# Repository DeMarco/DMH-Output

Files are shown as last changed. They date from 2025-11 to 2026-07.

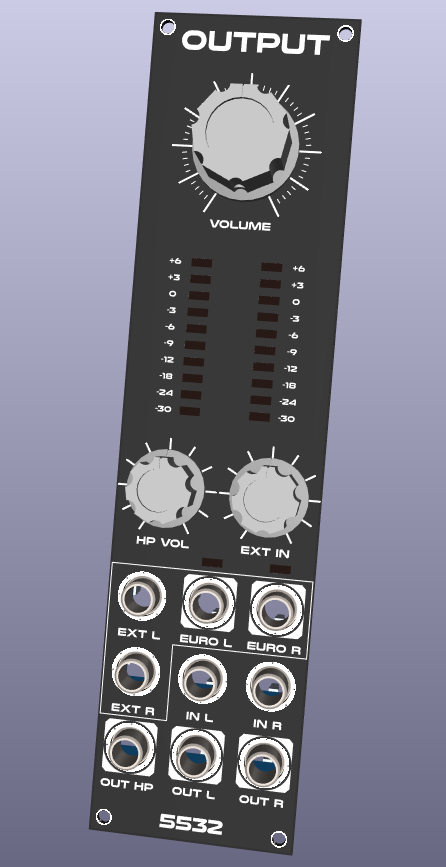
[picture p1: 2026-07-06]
Images/panel.png

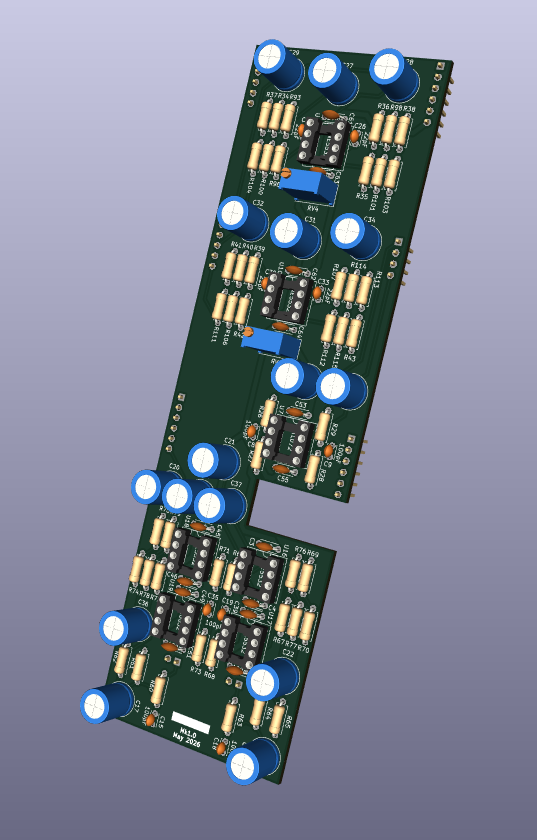
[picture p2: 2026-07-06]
Images/mezzanine_back.png

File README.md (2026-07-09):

# DMH-Output
Kosmo format output module







## Features

### Line outputs and main volume

The L and R inputs accept the usual (Eurorack) modular synth audio amplitude of 10 V peak-to-peak.
The line level L and R outputs accept both balanced TRS and unbalanced TS cables.
The main volume control affects both L and R channels. The reduction factor can be set from from -infinite (silence) to -3 dB (max).
Since the usual 10 Vpp amplitude corresponds to around +13 dBu, this means the module can output from -infinite up to +10 dBu.
The precision dBu meter will max out at +6 dBu (red LED). Most professional audio equipment like mixers and audio interfaces expect a nominal input line level of +4 dBu.

### Headphone output

There's a separate stereo (TRS) headphone driving output with its own volume control, also with a range of -infinite to +10 dBu.
It can drive headphones with 32ohms or 85ohms with no problem. Higher impedances are also probably fine.

### External instrument inputs

The external inputs can amplify line level signals to the usual Eurorack amplitude of 10 Vpp with the help of a dedicated volume control. The input metering LEDs will turn yellow when the amplified signals at the Euro L and R outputs is between 9 and 11 Vpp, and red when above 11 Vpp.
This pre-amp has been designed with line level signals in mind, like those coming from another synthesizer or professional audio equipment. High impedance instrument outputs like electric guitars might not produce the best sound when connected directly to this module.

## Current consumption

+12V --> 110mA

-12V --> 110mA

## Dimensions

Height: 20cm

Width: 5cm

Depth: 5cm

## PCB set

- Front Panel
- Controls
- LEDs Aligner
- Main
- Mezzanine

## Gerbers

https://github.com/DeMarco/DMH-Output/tree/main/Gerbers

## Schematic and BoM

https://github.com/DeMarco/DMH-Output/blob/main/DMH_Output_Schematic.pdf

https://github.com/DeMarco/DMH-Output/blob/main/DMH_Output_BoM.csv

## Assembly and Calibration Instructions

https://github.com/DeMarco/DMH-Output/blob/main/Assembly_Instructions.md

## Font

For viewing/customizing in KiCad, I recommend downloading and installing the Nulshock font from Typodermic: https://typodermicfonts.com/nulshock/

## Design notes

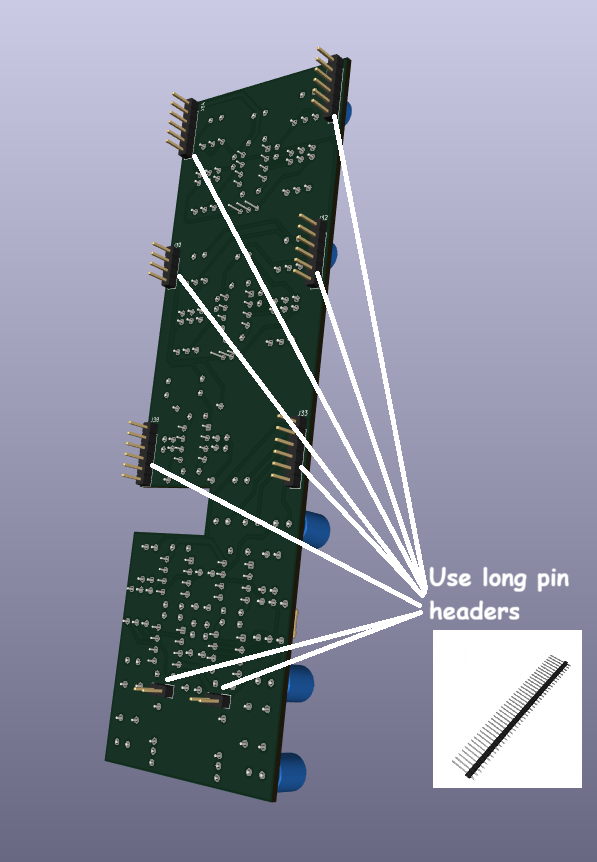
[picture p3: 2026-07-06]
Images/mezzanine_front.png

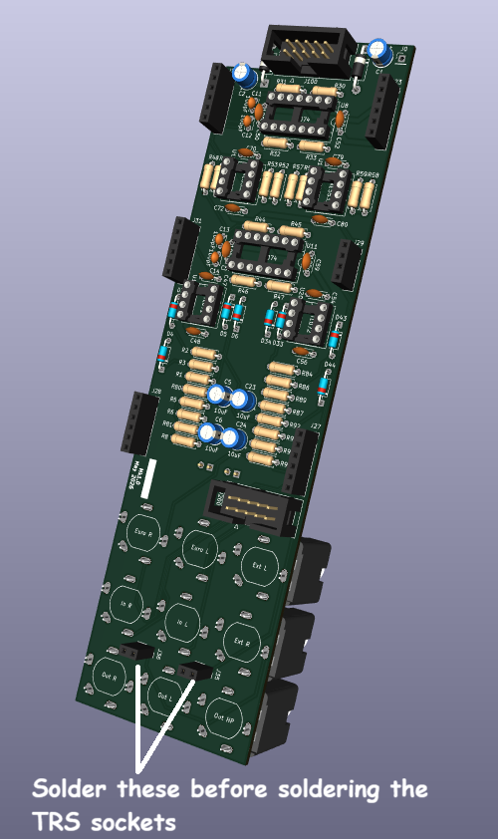
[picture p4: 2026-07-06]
Images/main_back.png

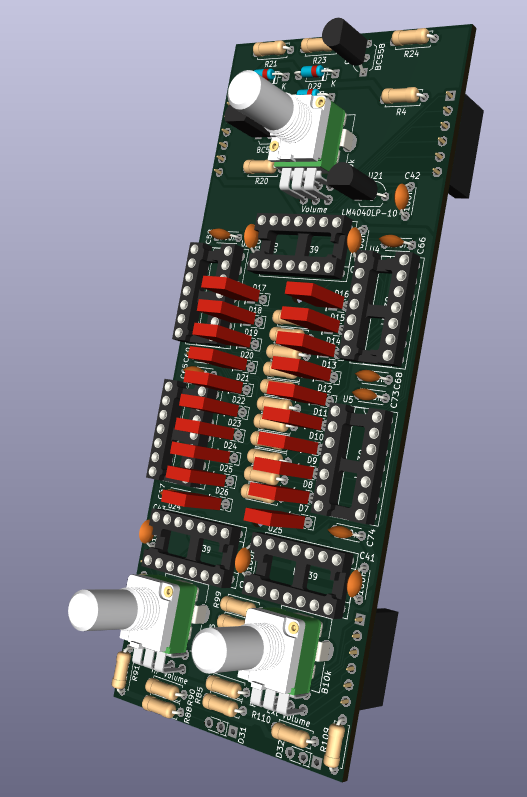
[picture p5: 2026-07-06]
Images/controls_front.png

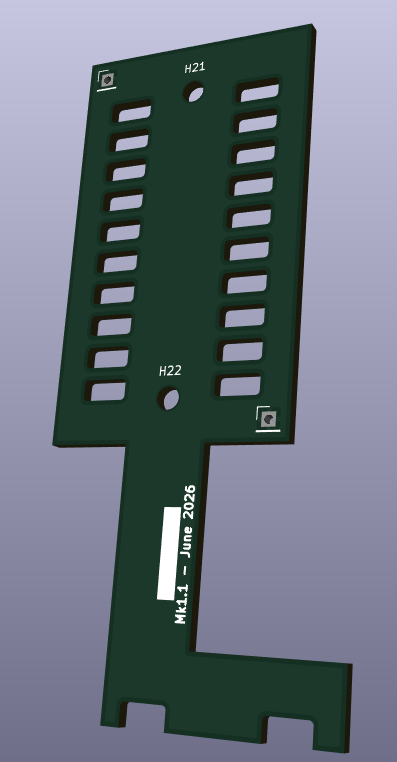
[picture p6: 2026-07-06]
Images/LED_aligner.png

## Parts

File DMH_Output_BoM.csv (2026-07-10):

Reference | Value | Qty | Footprint
C8,C9,C11,C12,C13,C14,C15,C18,C19,C35 | 100pF | 10 | Capacitor_THT:C_Disc_D3.0mm_W2.0mm_P2.50mm
C25,C26,C30,C33 | 22pF 50V | 4 | Capacitor_THT:C_Disc_D3.0mm_W2.0mm_P2.50mm
C3,C4,C39,C40,C41,C42,C43,C44,C45,C46,C47,C48,C49,C50,C51,C52,C53,C54,C55,C56,C57,C58,C59,C60,C61,C62,C63,C64,C65,C66,C67,C68,C70,C72,C73,C74,C77,C78,C79,C80 | 100nF | 40 | Capacitor_THT:C_Disc_D4.3mm_W1.9mm_P5.00mm
C16,C17,C20,C21 | 22uF 35V | 4 | Capacitor_THT:C_Radial_D8.0mm_H11.5mm_P3.50mm | Nichikon non-polarized
C7,C10,C22,C27,C28,C29,C31,C32,C34,C36,C37,C38 | 47uF 35V | 12 | Capacitor_THT:C_Radial_D8.0mm_H11.5mm_P3.50mm | Nichikon non-polarized
C5,C6,C23,C24 | 10uF | 4 | Capacitor_THT:CP_Radial_D5.0mm_P2.00mm
C1,C2 | 47uF | 2 | Capacitor_THT:CP_Radial_D5.0mm_P2.00mm
J24,J25 | Conn_01x02 | 2 | Connector_PinHeader_2.54mm:PinHeader_1x02_P2.54mm_Vertical
J39,J40 | Conn_01x02_PinHeader | 2 | Connector_PinHeader_2.54mm:PinHeader_1x02_P2.54mm_Vertical
J30 | Conn_01x04_PinHeader | 1 | Connector_PinHeader_2.54mm:PinHeader_1x04_P2.54mm_Vertical
J33,J34,J37,J38 | Conn_01x06 | 4 | Connector_PinHeader_2.54mm:PinHeader_1x06_P2.54mm_Vertical
J32 | Conn_01x06_PinHeader | 1 | Connector_PinHeader_2.54mm:PinHeader_1x06_P2.54mm_Vertical
J21,J22 | Conn_01x02 | 2 | Connector_PinSocket_2.54mm:PinSocket_1x02_P2.54mm_Vertical
J35,J36 | Conn_01x02_PinHeader | 2 | Connector_PinSocket_2.54mm:PinSocket_1x02_P2.54mm_Vertical
J29 | Conn_01x04_PinHeader | 1 | Connector_PinSocket_2.54mm:PinSocket_1x04_P2.54mm_Vertical
J10,J13,J23,J28 | Conn_01x06 | 4 | Connector_PinSocket_2.54mm:PinSocket_1x06_P2.54mm_Vertical
J11,J12,J26,J27,J31 | Conn_01x06_PinHeader | 5 | Connector_PinSocket_2.54mm:PinSocket_1x06_P2.54mm_Vertical
D3,D4,D5,D6,D27,D28,D29,D30,D33,D34,D43,D44 | 1N4148 | 12 | Diode_THT:D_DO-35_SOD27_P7.62mm_Horizontal
D1,D2 | SB140 | 2 | Diode_THT:D_DO-41_SOD81_P10.16mm_Horizontal
D7,D8,D9,D10,D11,D12,D13,D20,D21,D22,D23,D24,D25,D26 | LED_G | 14 | LED_THT:LED_Rectangular_W5.0mm_H2.0mm
D16,D17 | LED_R | 2 | LED_THT:LED_Rectangular_W5.0mm_H2.0mm
D14,D15,D18,D19 | LED_Y | 4 | LED_THT:LED_Rectangular_W5.0mm_H2.0mm
D31,D32 | LED_Dual_AKA | 2 | LED_THT:LED_Rectangular_W5.0mm_H2.0mm-3Pins
U2,U3,U4,U5,U6,U24,U25 | LM339 | 7 | Package_DIP:DIP-14_W7.62mm_Socket
U8,U11 | TL074 | 2 | Package_DIP:DIP-14_W7.62mm_Socket
U9,U10,U13,U15,U16,U17,U18,U19 | NE5532 | 8 | Package_DIP:DIP-8_W7.62mm_Socket
U1,U7,U20 | TL072 | 3 | Package_DIP:DIP-8_W7.62mm_Socket
Q1,Q2 | BC558 | 2 | Package_TO_SOT_THT:TO-92L_Inline_Wide
U21 | LM4040LP-10 | 1 | Package_TO_SOT_THT:TO-92L_Inline_Wide
RV4,RV5 | 1k | 2 | Potentiometer_THT:Potentiometer_Bourns_3296W_Vertical
R52,R53,R58,R59 | 10R | 4 | Resistor_THT:R_Axial_DIN0207_L6.3mm_D2.5mm_P7.62mm_Horizontal
R21,R23 | 47R | 2 | Resistor_THT:R_Axial_DIN0207_L6.3mm_D2.5mm_P7.62mm_Horizontal
R37,R38,R41,R113 | 75R | 4 | Resistor_THT:R_Axial_DIN0207_L6.3mm_D2.5mm_P7.62mm_Horizontal
R60,R63,R70,R74 | 100R | 4 | Resistor_THT:R_Axial_DIN0207_L6.3mm_D2.5mm_P7.62mm_Horizontal
R18,R19 | 361R | 2 | Resistor_THT:R_Axial_DIN0207_L6.3mm_D2.5mm_P7.62mm_Horizontal
R3,R6,R86,R94 | 470R | 4 | Resistor_THT:R_Axial_DIN0207_L6.3mm_D2.5mm_P7.62mm_Horizontal
R17 | 715R | 1 | Resistor_THT:R_Axial_DIN0207_L6.3mm_D2.5mm_P7.62mm_Horizontal
R30,R31,R32,R33,R43,R44,R46,R48,R49,R56,R57,R67,R72,R103,R104,R108,R111 | 1k | 17 | Resistor_THT:R_Axial_DIN0207_L6.3mm_D2.5mm_P7.62mm_Horizontal
R15 | 1k2 | 1 | Resistor_THT:R_Axial_DIN0207_L6.3mm_D2.5mm_P7.62mm_Horizontal
R16 | 1k43 | 1 | Resistor_THT:R_Axial_DIN0207_L6.3mm_D2.5mm_P7.62mm_Horizontal
R14 | 1k69 | 1 | Resistor_THT:R_Axial_DIN0207_L6.3mm_D2.5mm_P7.62mm_Horizontal
R76,R77,R78,R79 | 2k | 4 | Resistor_THT:R_Axial_DIN0207_L6.3mm_D2.5mm_P7.62mm_Horizontal
R13 | 2k37 | 1 | Resistor_THT:R_Axial_DIN0207_L6.3mm_D2.5mm_P7.62mm_Horizontal
R4,R12,R88,R90,R109,R110 | 3k3 | 6 | Resistor_THT:R_Axial_DIN0207_L6.3mm_D2.5mm_P7.62mm_Horizontal
R11,R34,R35,R40,R42,R96,R98,R112,R114 | 4k7 | 9 | Resistor_THT:R_Axial_DIN0207_L6.3mm_D2.5mm_P7.62mm_Horizontal
R10 | 6k8 | 1 | Resistor_THT:R_Axial_DIN0207_L6.3mm_D2.5mm_P7.62mm_Horizontal
R36,R39,R45,R47,R68,R73,R93,R100,R101,R102,R106,R107,R115 | 10k | 13 | Resistor_THT:R_Axial_DIN0207_L6.3mm_D2.5mm_P7.62mm_Horizontal
R27,R28 | 14k | 2 | Resistor_THT:R_Axial_DIN0207_L6.3mm_D2.5mm_P7.62mm_Horizontal
R26,R29 | 20k | 2 | Resistor_THT:R_Axial_DIN0207_L6.3mm_D2.5mm_P7.62mm_Horizontal
R1,R2,R5,R8,R20,R24,R66,R71,R84,R89,R92,R97 | 22k | 12 | Resistor_THT:R_Axial_DIN0207_L6.3mm_D2.5mm_P7.62mm_Horizontal
R99,R105 | 47k | 2 | Resistor_THT:R_Axial_DIN0207_L6.3mm_D2.5mm_P7.62mm_Horizontal
R80,R81 | 68k | 2 | Resistor_THT:R_Axial_DIN0207_L6.3mm_D2.5mm_P7.62mm_Horizontal
R87,R95 | 68K | 2 | Resistor_THT:R_Axial_DIN0207_L6.3mm_D2.5mm_P7.62mm_Horizontal
R9 | 82k | 1 | Resistor_THT:R_Axial_DIN0207_L6.3mm_D2.5mm_P7.62mm_Horizontal
R62,R65,R69,R75,R85,R91 | 100k | 6 | Resistor_THT:R_Axial_DIN0207_L6.3mm_D2.5mm_P7.62mm_Horizontal
R61,R64 | 220k | 2 | Resistor_THT:R_Axial_DIN0207_L6.3mm_D2.5mm_P7.62mm_Horizontal
J1,J2,J3,J4,J5,J6,J7,J8,J9 | TRS_Jack_6.35mm_Sw | 9 | SynthStuff:CUI_SJ-63083D
J200 | IDC_02x05 | 1 | SynthStuff:IDC-Header_2x05_P2.54mm_Vertical_BackBone
J100 | IDC_02x05 | 1 | SynthStuff:IDC-Header_2x05_P2.54mm_Vertical_Eurorack
RV1,RV2,RV3 | B10k | 3 | SynthStuff:Potentiometer_Alpha_RD902F-40-00D_Dual_Vertical
DIP socket 8 pins | DIP-8_W7.62mm_Socket | 11
DIP socket 14 pins | DIP-14_W7.62mm_Socket | 9
Standoff | 5mm, M2.5 | 2
Standoff nut | M2.5 | 2
Standoff screw | M2.5 | 2

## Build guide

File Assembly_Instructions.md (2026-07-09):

# Output Module - Instructions

## Schematic and BoM

https://github.com/DeMarco/DMH-Output/blob/main/DMH_Output_Schematic.pdf

https://github.com/DeMarco/DMH-Output/blob/main/DMH_Output_BoM.csv

## Soldering

### Main PCB:

Solder these components in the following order:

- Resistors
- Diodes
- IC sockets
- Ceramic capacitors
- Electrolytic capacitors
- Power (J100) and IO (J200) connectors
- Pin sockets for PCB stacking (use 11mm stackable sockets on J23, J26, J27 and J28)
- TRS jack sockets

*__Tip:__* don't forget to solder pin sockets J35 and J36 before the TRS jack sockets. This is very hard to rework if not done in this order.

main_front
main_back

### Mezzanine PCB:

Solder these components in the following order:

- Resistors
- IC sockets
- Ceramic capacitors
- Trimpots
- Electrolytic capacitors
- Pin headers for PCB stacking (use 11mm long pin headers to avoid volume conflicts)

mezzanine_front
mezzanine_back

### Controls PCB:

Solder these components in the following order:

- Resistors
- IC sockets
- Ceramic capacitors
- Transistors and LM4040 regulator
- Potentiometers
- _Don't solder the LEDs and pin sockets yet_

controls_front

Once the potentiometers are secured, make use of 2x 5mm standoffs to secure the LED Aligner PCB in place.
The LED Aligner will be flush with the IC sockets, but this is expected. It will be removed later to make space for the ICs.




Insert the LEDs through the holes of the LED Aligner. Make sure the shorter terminals are inserted into the square solder pads on the PCB:



Now, attach the Front Panel and secure it in place with the potentiometers' nuts:



Flip the assembly so that gravity pulls the LEDs downwards. Make sure all LEDs are well aligned and flush with the back of the Front Panel:
(don't forget the 3-pin LEDs D31 and D32, which are missing in the picture!!)



Solder all LED terminals and unscrew the Front Panel. This should be the result:



Remove the LED Alginer PCB and the standoffs.

Now finish the Controls PCB by soldering the pin sockets for PCB stacking.

controls_back

## Voltage Supply Testing

Without inserting the ICs in their sockets, stack all PCBs together.

*__Tip:__* If necessary, "thicken" the pins of the stacking sockets with a bit of solder, in case you suspect they are not making contact.



Set your multimeter in continuinity test mode.

Make sure all TRS jack socket barrels are well connected to GND.

*__Tip:__* Pad J0 close to C1 on the Main PCB can be used as a helpful GND terminal for any measurements.



Connect the power cable to J100 and switch on your power supply.

Make sure there's no magic smoke nor excessive heat coming from any component.

Use a multimeter to check if +12V and -12V supply voltages are correct on the IC sockets.

*__Tip:__* Temporarily unstack the Mezzanine PCB to allow measuring on the Main PCB IC sockets.

Measure also the +10V reference voltage on the top terminal of C42 on the Controls PCB.



## Final Assembly

Power off the module.

Insert all ICs in their respective sockets.

*__Tip:__* Make sure to align the IC and socket grooves to avoid frying your precious chips.

Power the module back on.

Position the LED Aligner PCB on top of the ICs on the Controls PCB. No need to secure it with standoffs.

The Aligner should be flush with both the ICs and LEDs top surfaces. This will help reducing light bleeding from one LED to the other.



Finally, put the Front Panel in place and secure it agains the pots and TRS sockets with their respective washers and nuts.

Mount the knob covers. The module is now ready for calibration.

## Calibration

Power the module again, still on your bench.

Set all 3 knobs to the max (fully clockwise).

Check that the current consumption indicated by your power supply is about 110mA for both the +12V and -12V supply voltages.

Plug a realiable sawtooth wave signal to In L (like from a VCO). 

Make sure both channels 1 and 2 of your oscilloscope are centered on the 0V.

Attach channels 1 and 2 of the oscilloscope to test points TP21 and T22 respectively.

Adjust the oscilloscope for amplitude and frequency.

A 10Vpp sawtooth input signal (like that coming from a VCO) should result in a 7Vpp signal (thus +/-3.5V) at TP21. An inverted sawtooth signal of same amplitude should appear at TP22.

Adjust trimpot RV4 until both signals are "perfectly" centered around the 0V line.



Repeat the procedure for the Right channel by using In R, TP23, TP24 and RV5.



## Configuration

Connector J200 can be used to make the module's IO available at another PCB for internal "normalling" with other modules, like in a semimodular synthesizer.

When J200 is not in use, pins 1 and 6 can be joined together (with a jumper). This will "stereofy" a mono signal plugged to In L when In R is not in use.

The same can be done with pins 2 and 7 in order to "stereofy" a mono signal from an external instrument at the Euro L/R outputs.



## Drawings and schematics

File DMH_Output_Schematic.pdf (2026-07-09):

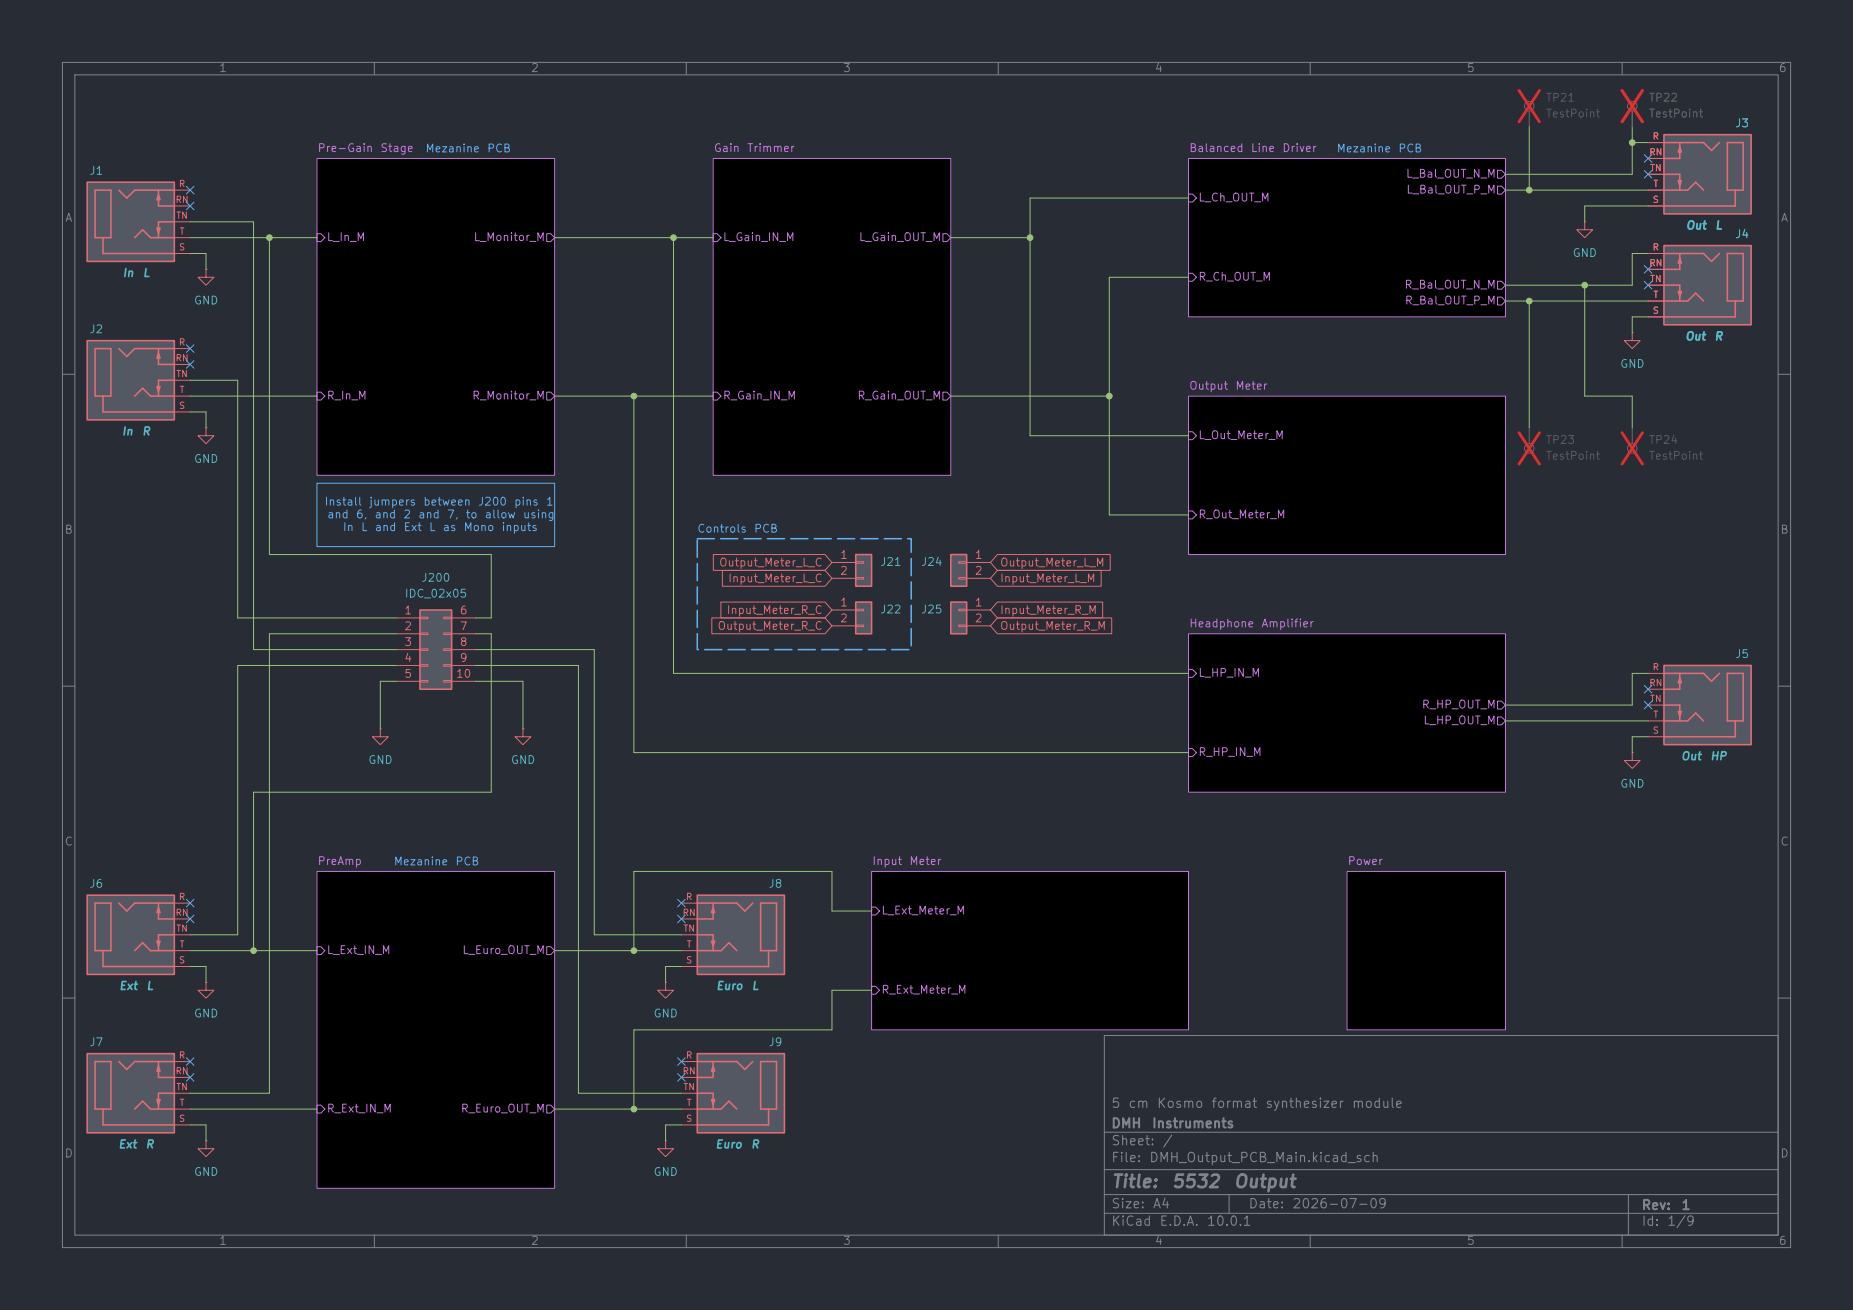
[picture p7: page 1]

Install jumpers between J200 pins 1
and 6, and 2 and 7, to allow using

5 | | 10

5 cm Kosmo format synthesizer module
DMH Instruments
Sheet: /
File: DMH_Output_PCB_Main.kicad_sch
Title: 5532 Output

Size: A4 | Rev: 1
KiCad E.D.A. 10.0.1 | Id: 1/9

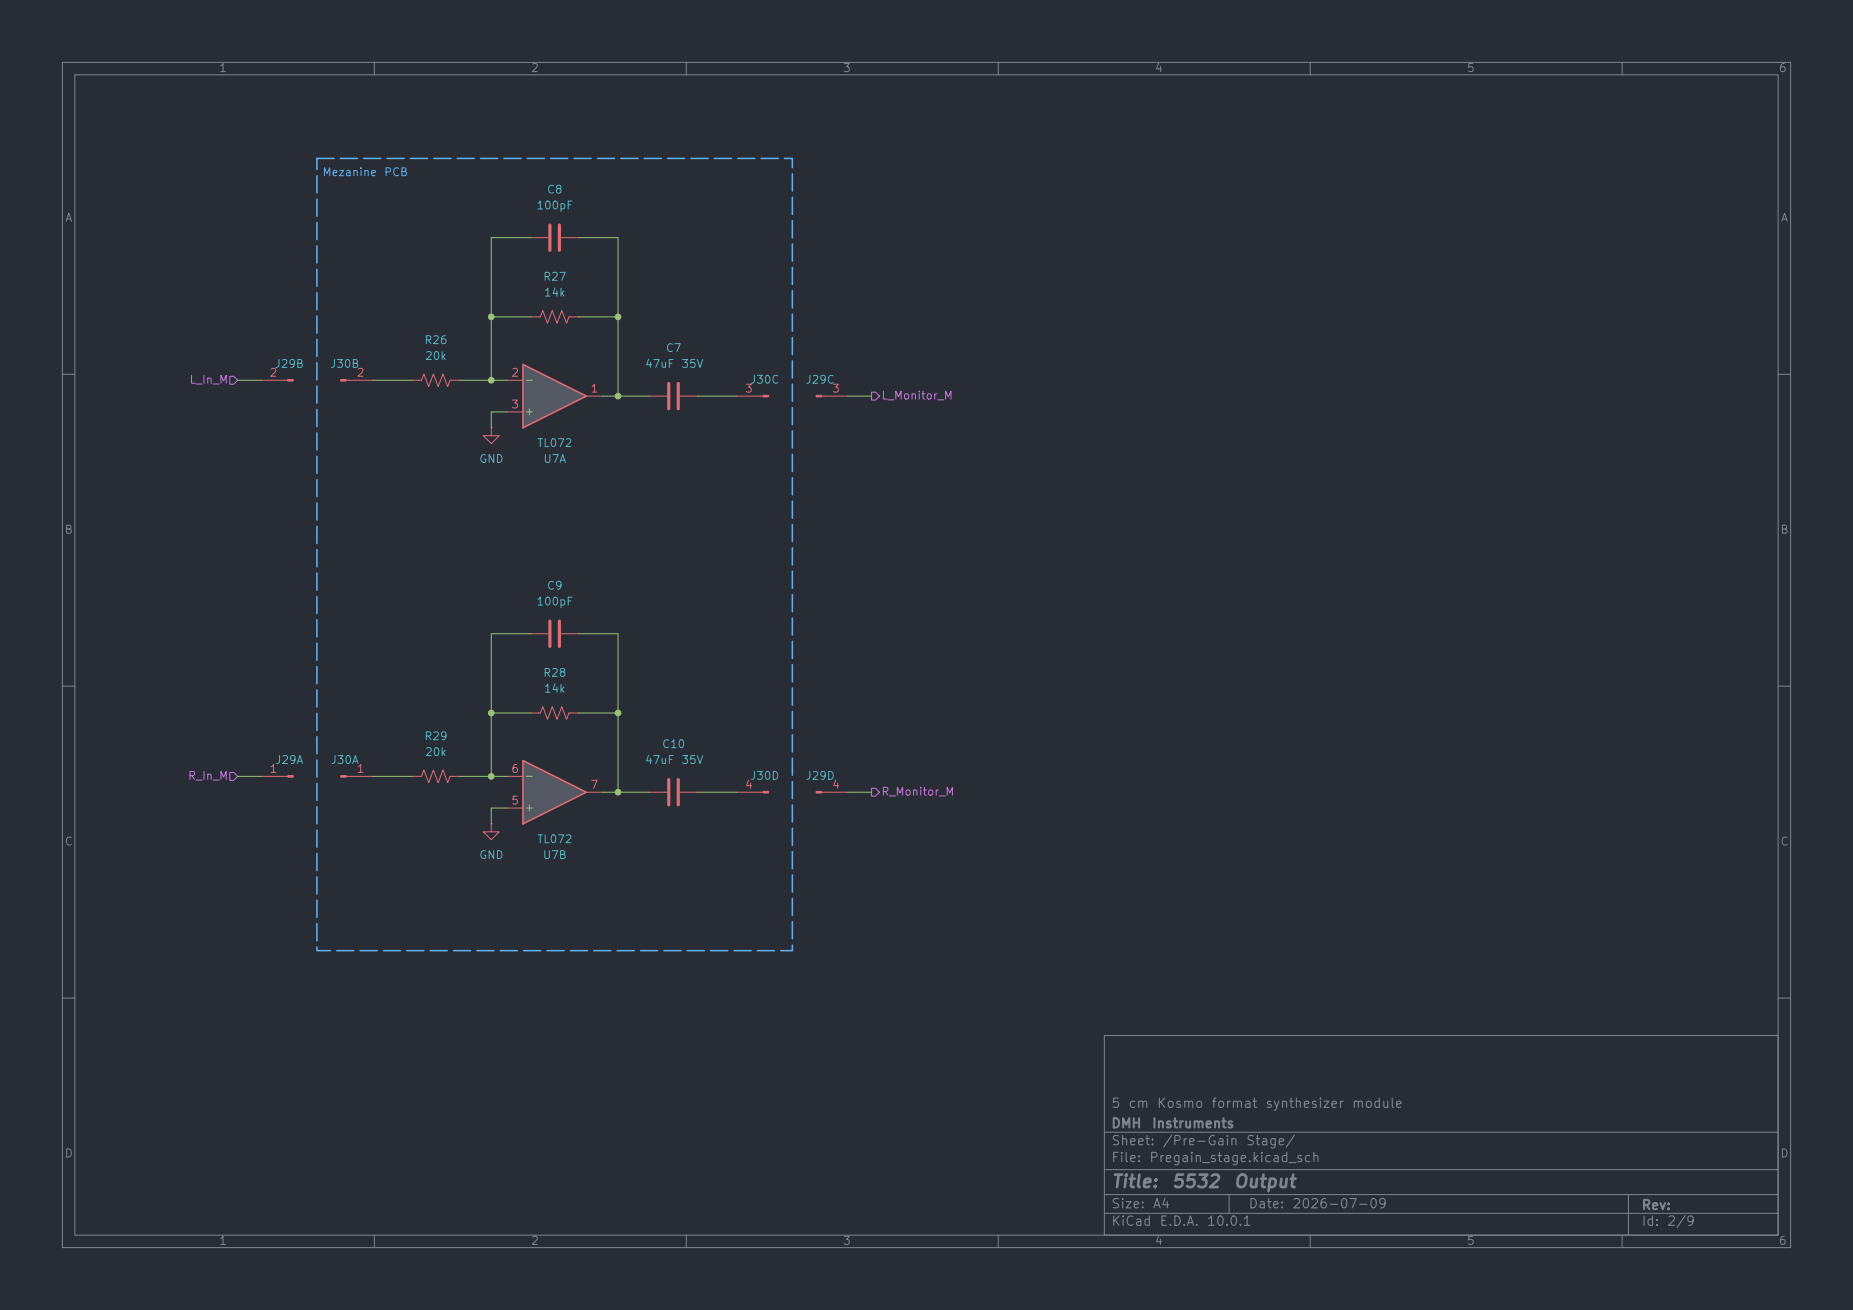
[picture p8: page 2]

5 cm Kosmo format synthesizer module
DMH Instruments
Sheet: /Pre-Gain Stage/
File: Pregain_stage.kicad_sch
Title: 5532 Output

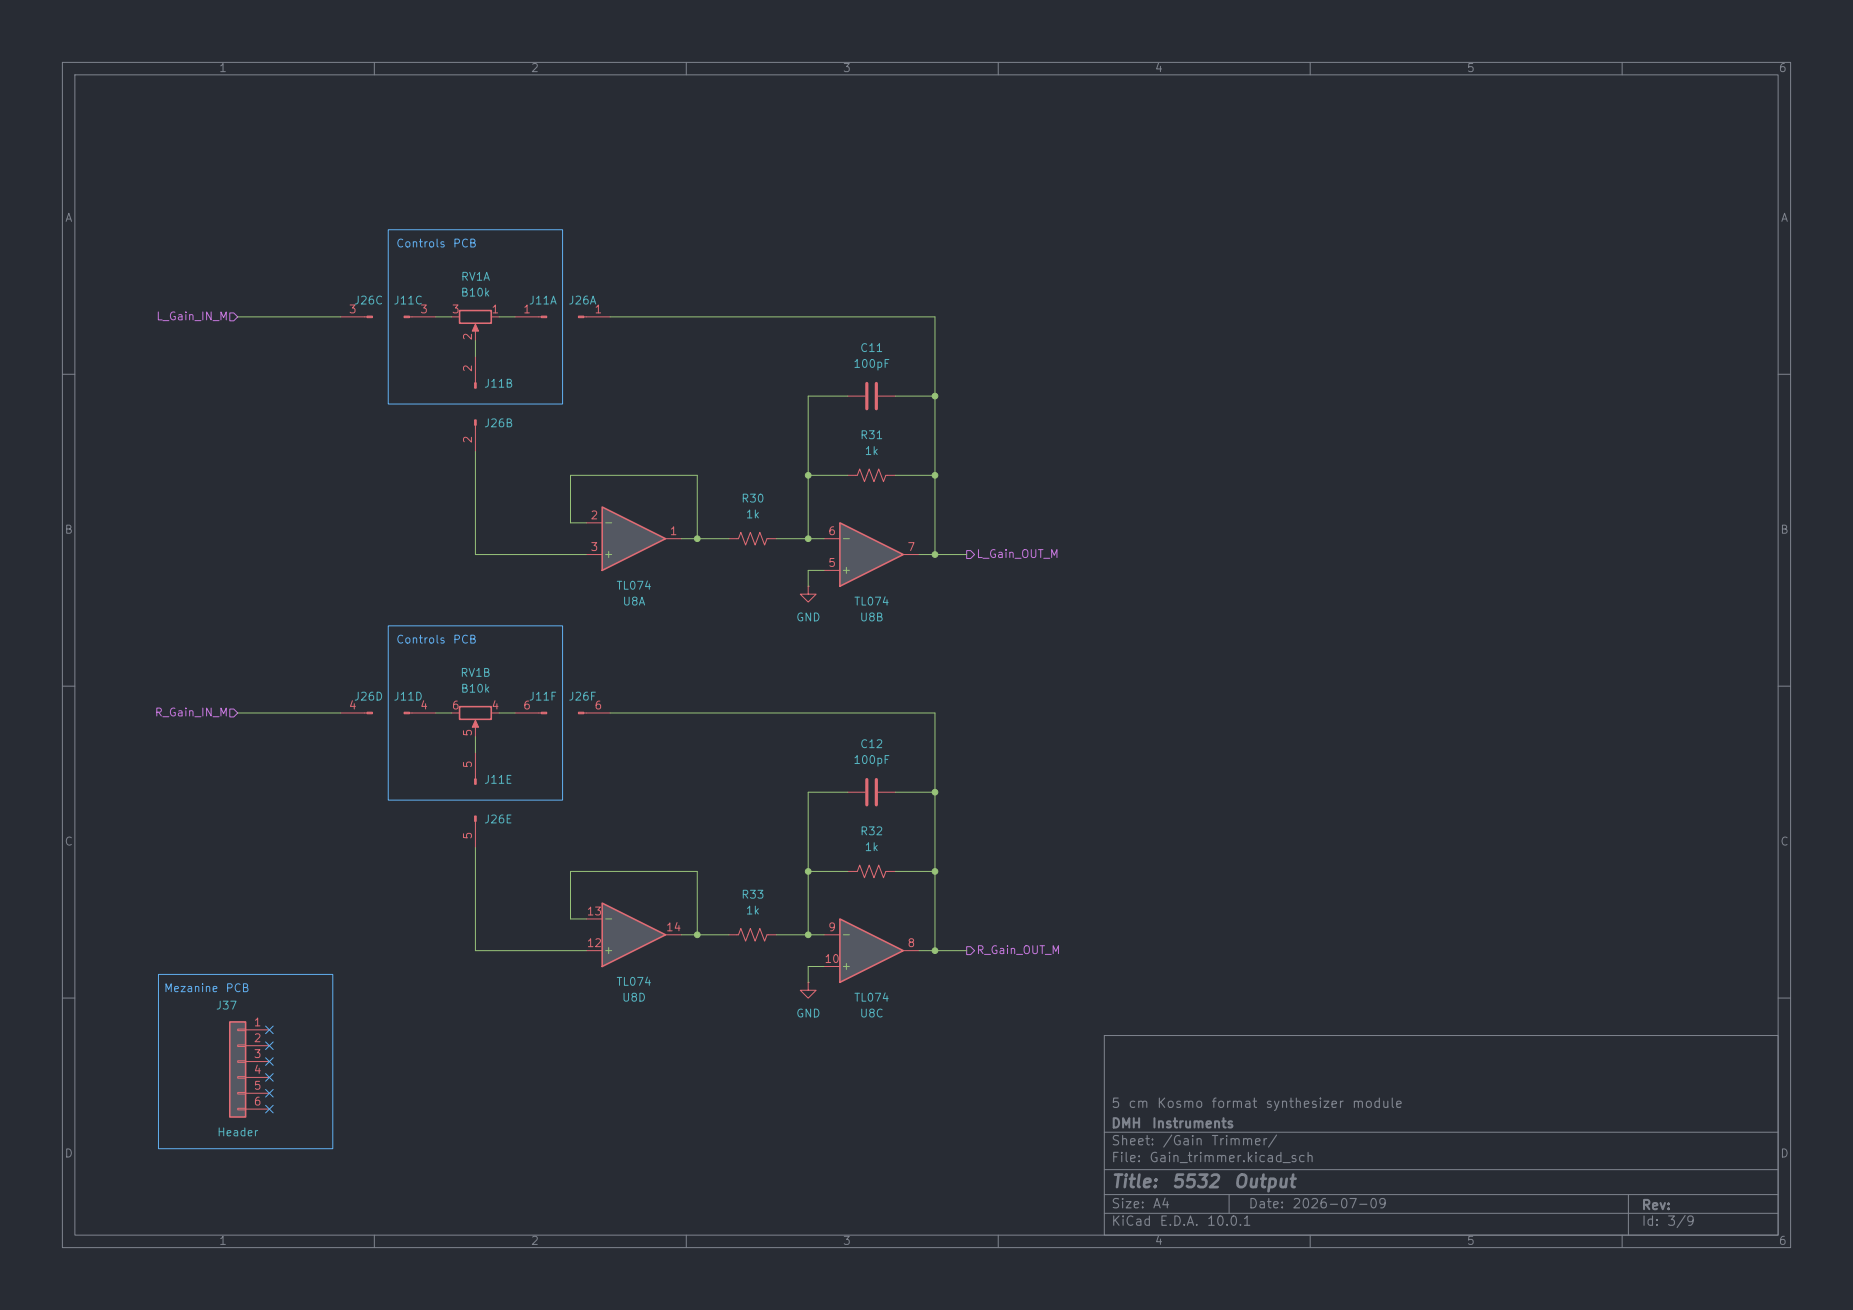
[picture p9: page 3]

Controls PCB Mezanine PCB

5 cm Kosmo format synthesizer module
DMH Instruments
Sheet: /Gain Trimmer/
File: Gain_trimmer.kicad_sch
Title: 5532 Output

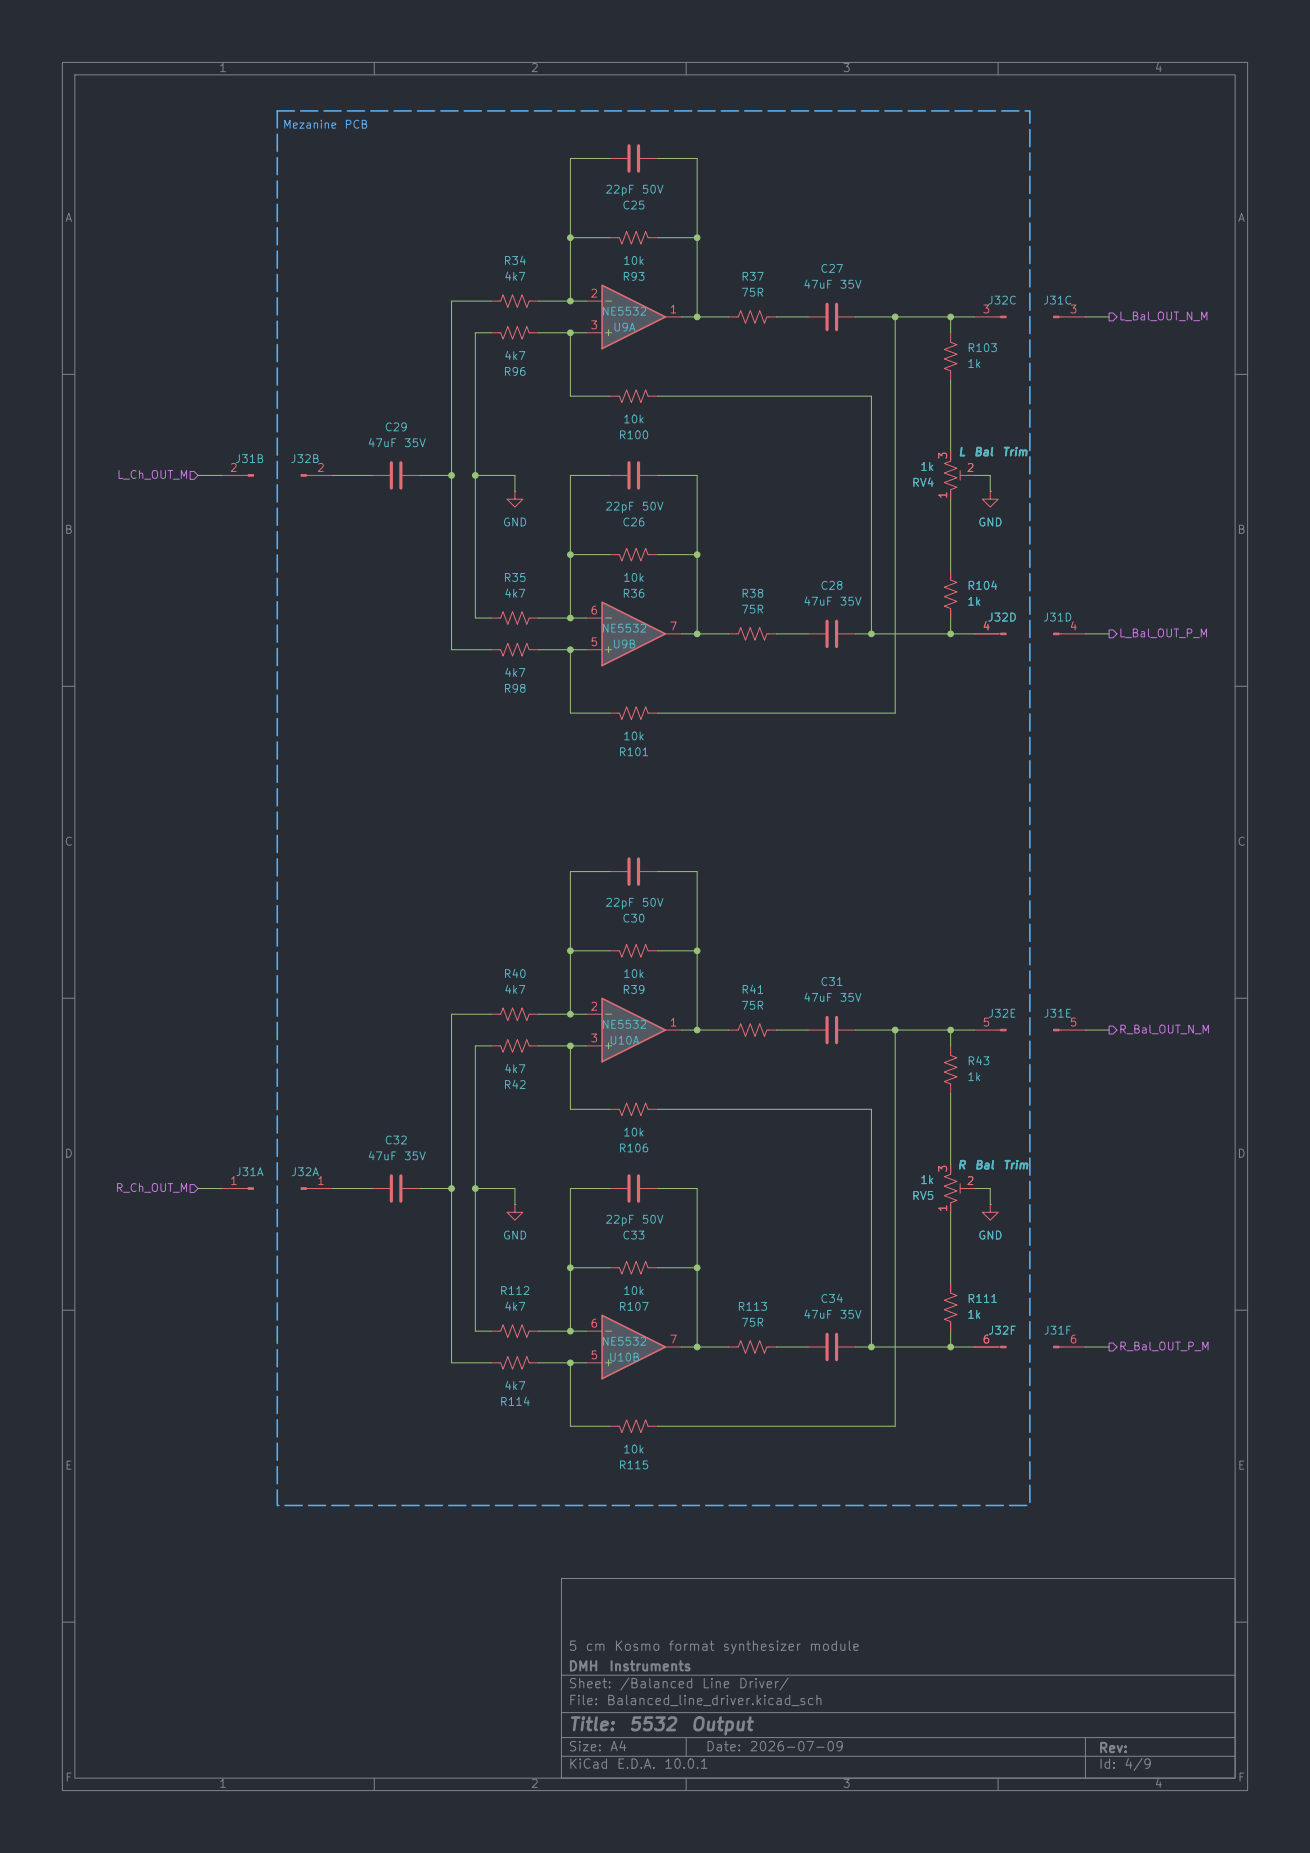
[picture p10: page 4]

5 cm Kosmo format synthesizer module
DMH Instruments
Sheet: /Balanced Line Driver/
File: Balanced_line_driver.kicad_sch
Title: 5532 Output

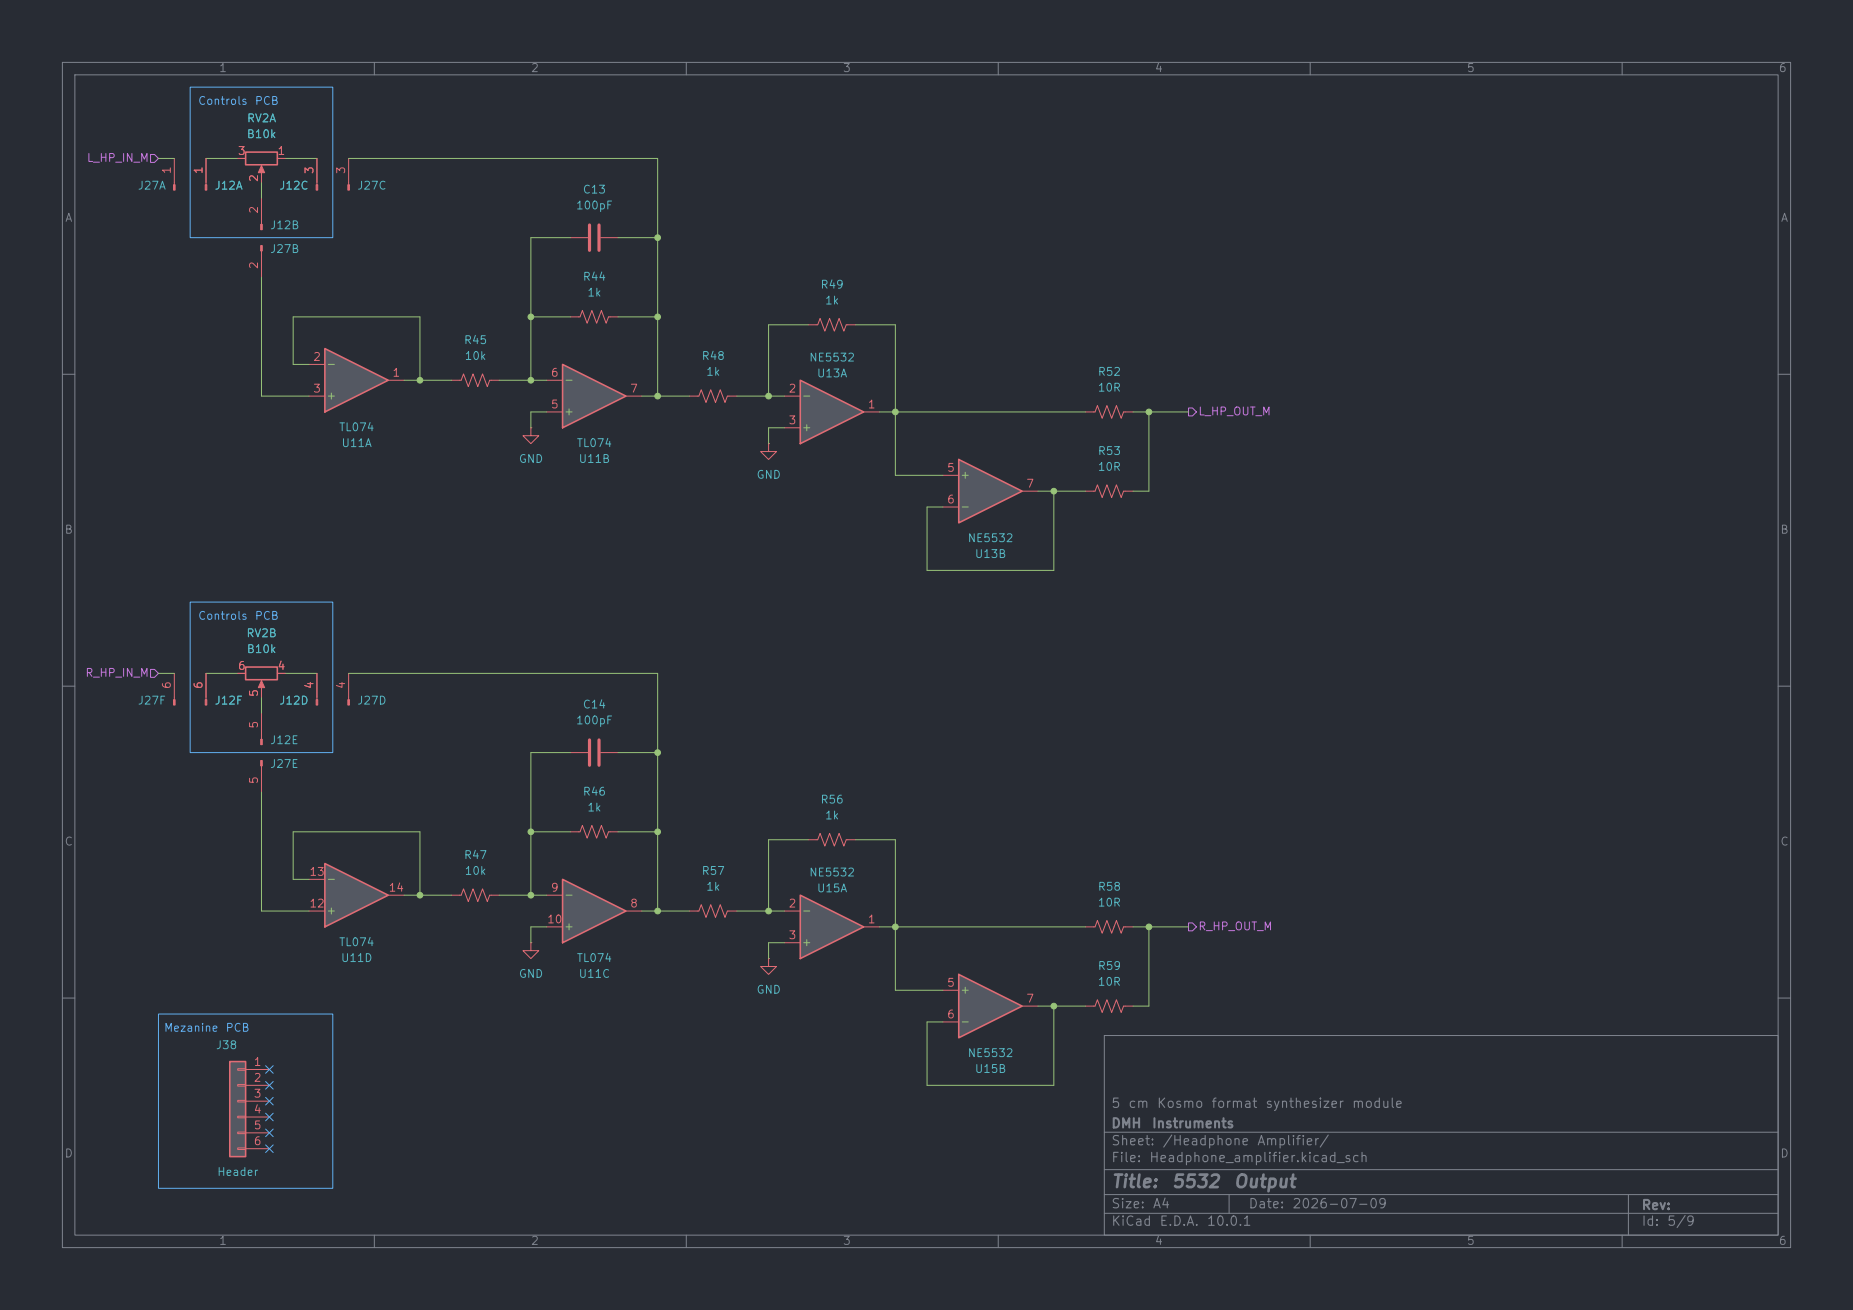
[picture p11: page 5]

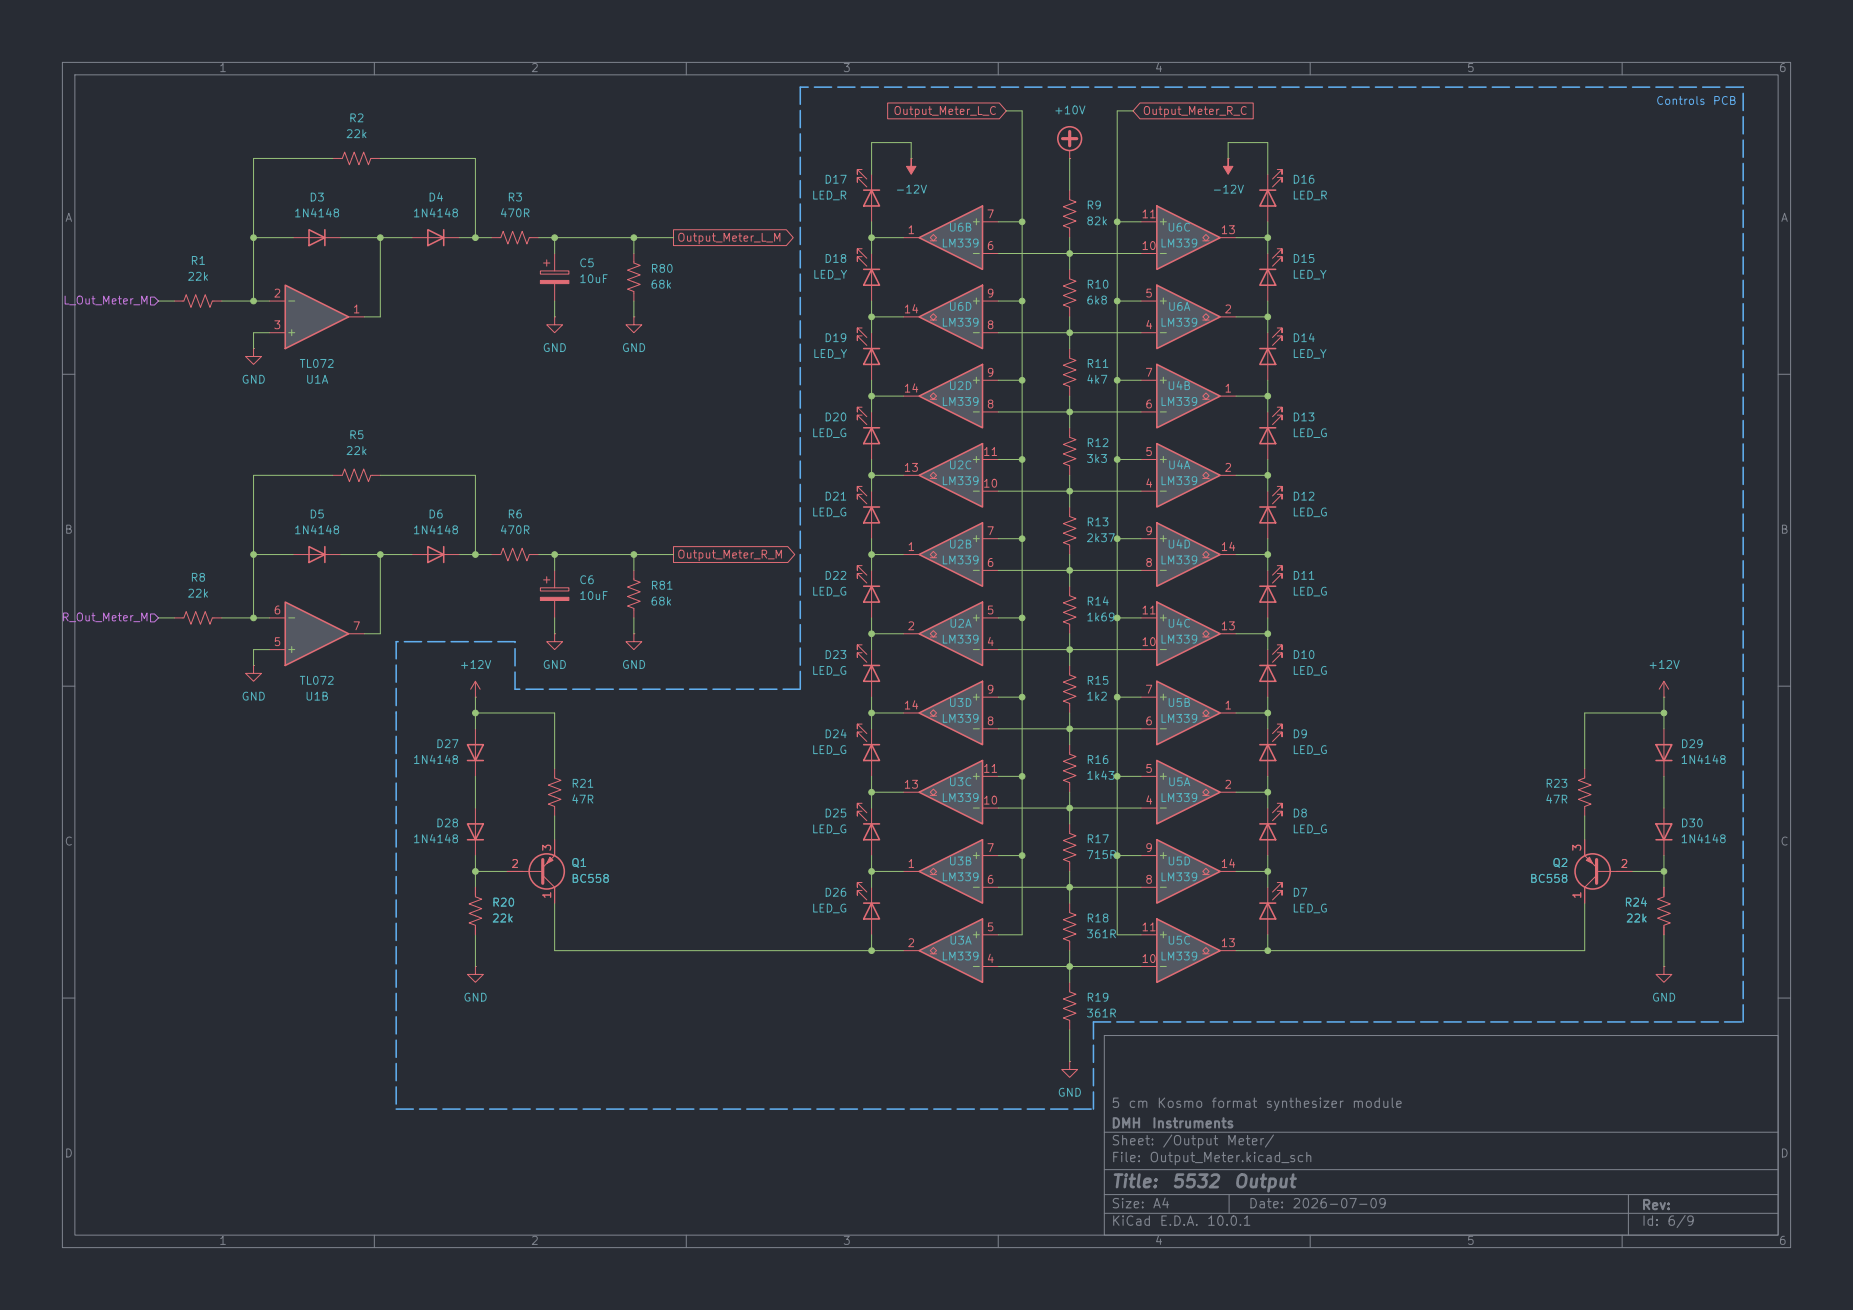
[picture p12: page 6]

5 cm Kosmo format synthesizer module
DMH Instruments
Sheet: /Output Meter/
File: Output_Meter.kicad_sch
Title: 5532 Output

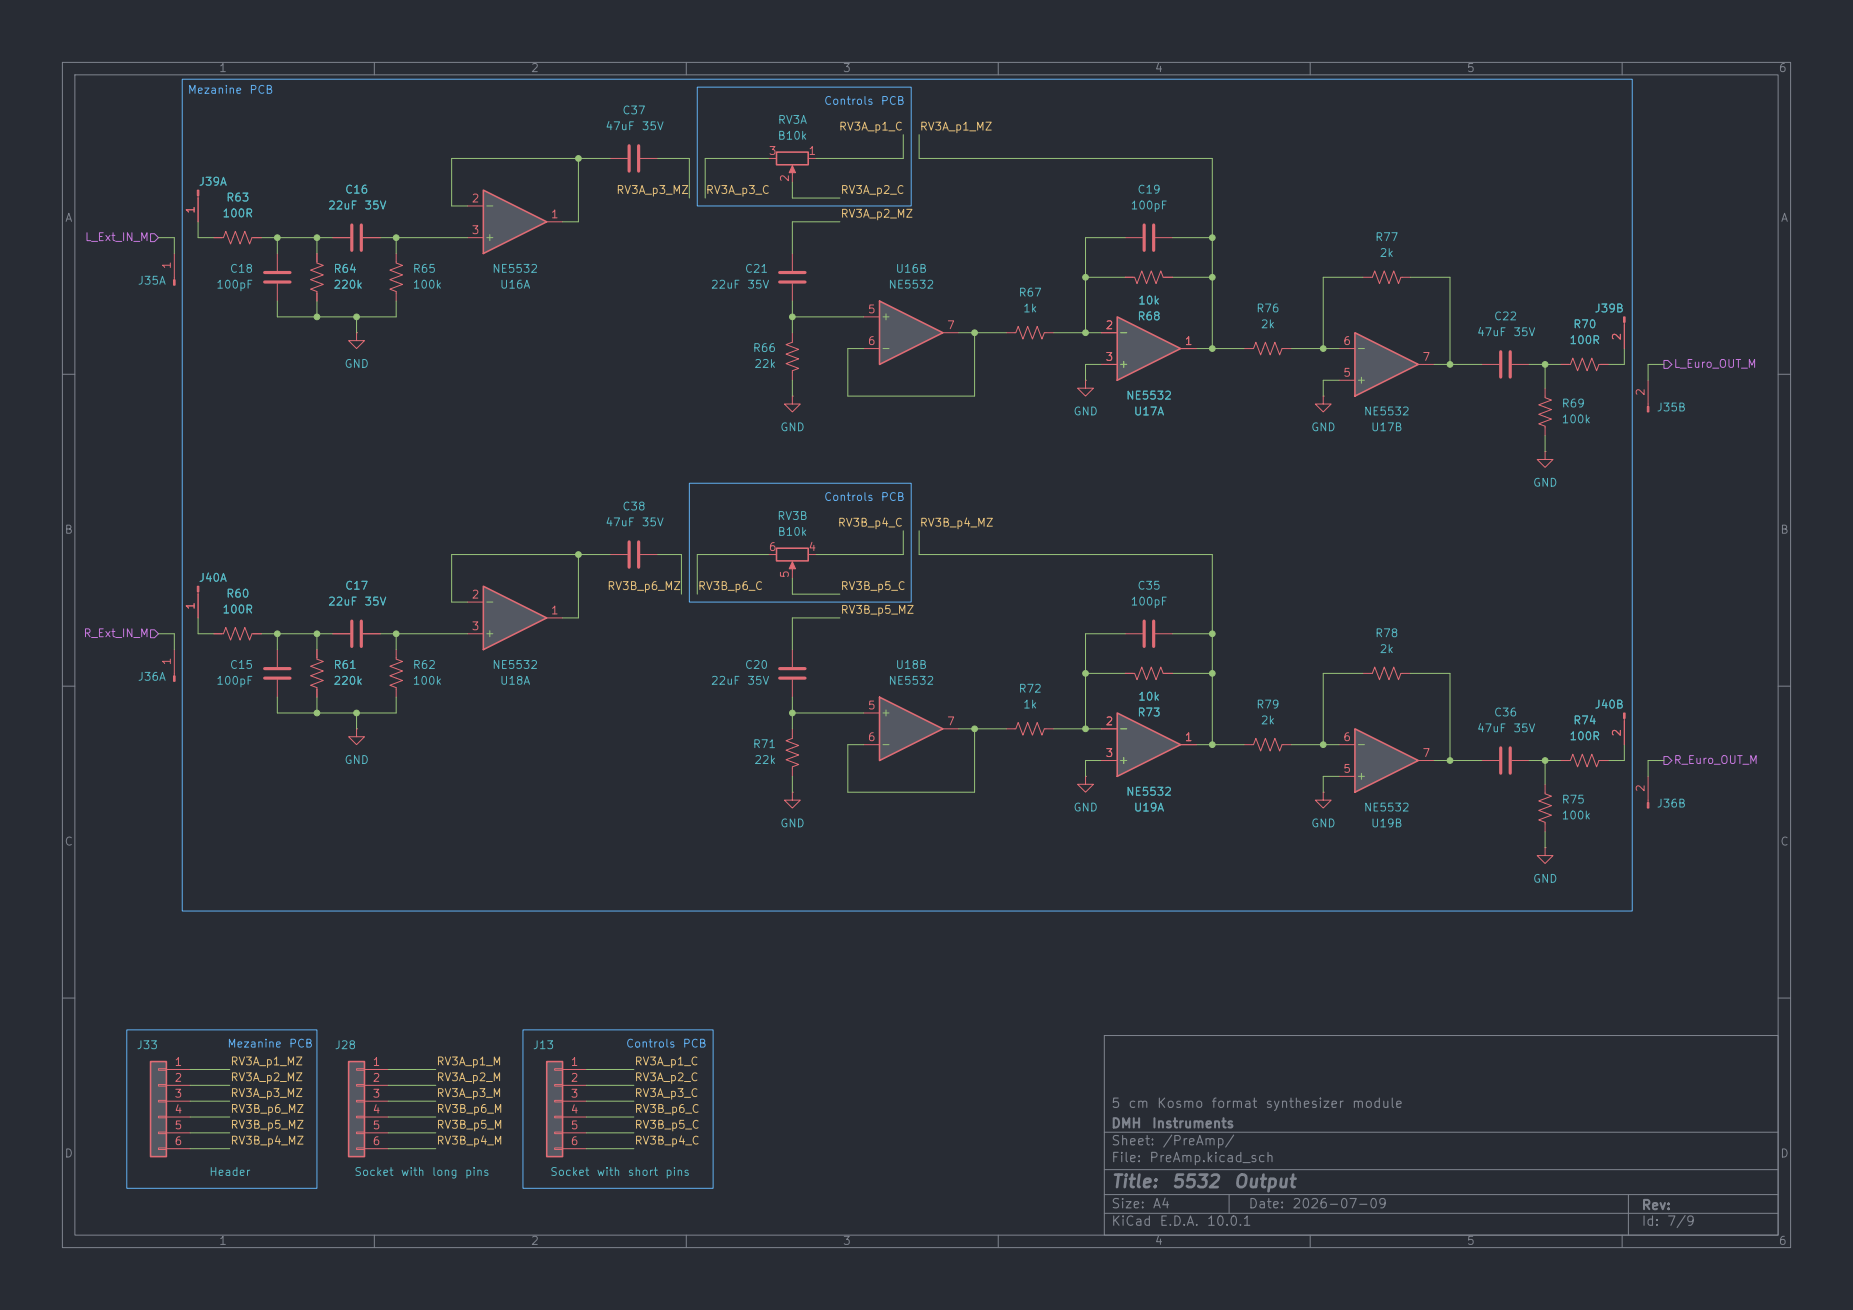
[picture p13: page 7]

5 cm Kosmo format synthesizer module
DMH Instruments
Sheet: /PreAmp/
File: PreAmp.kicad_sch
Title: 5532 Output

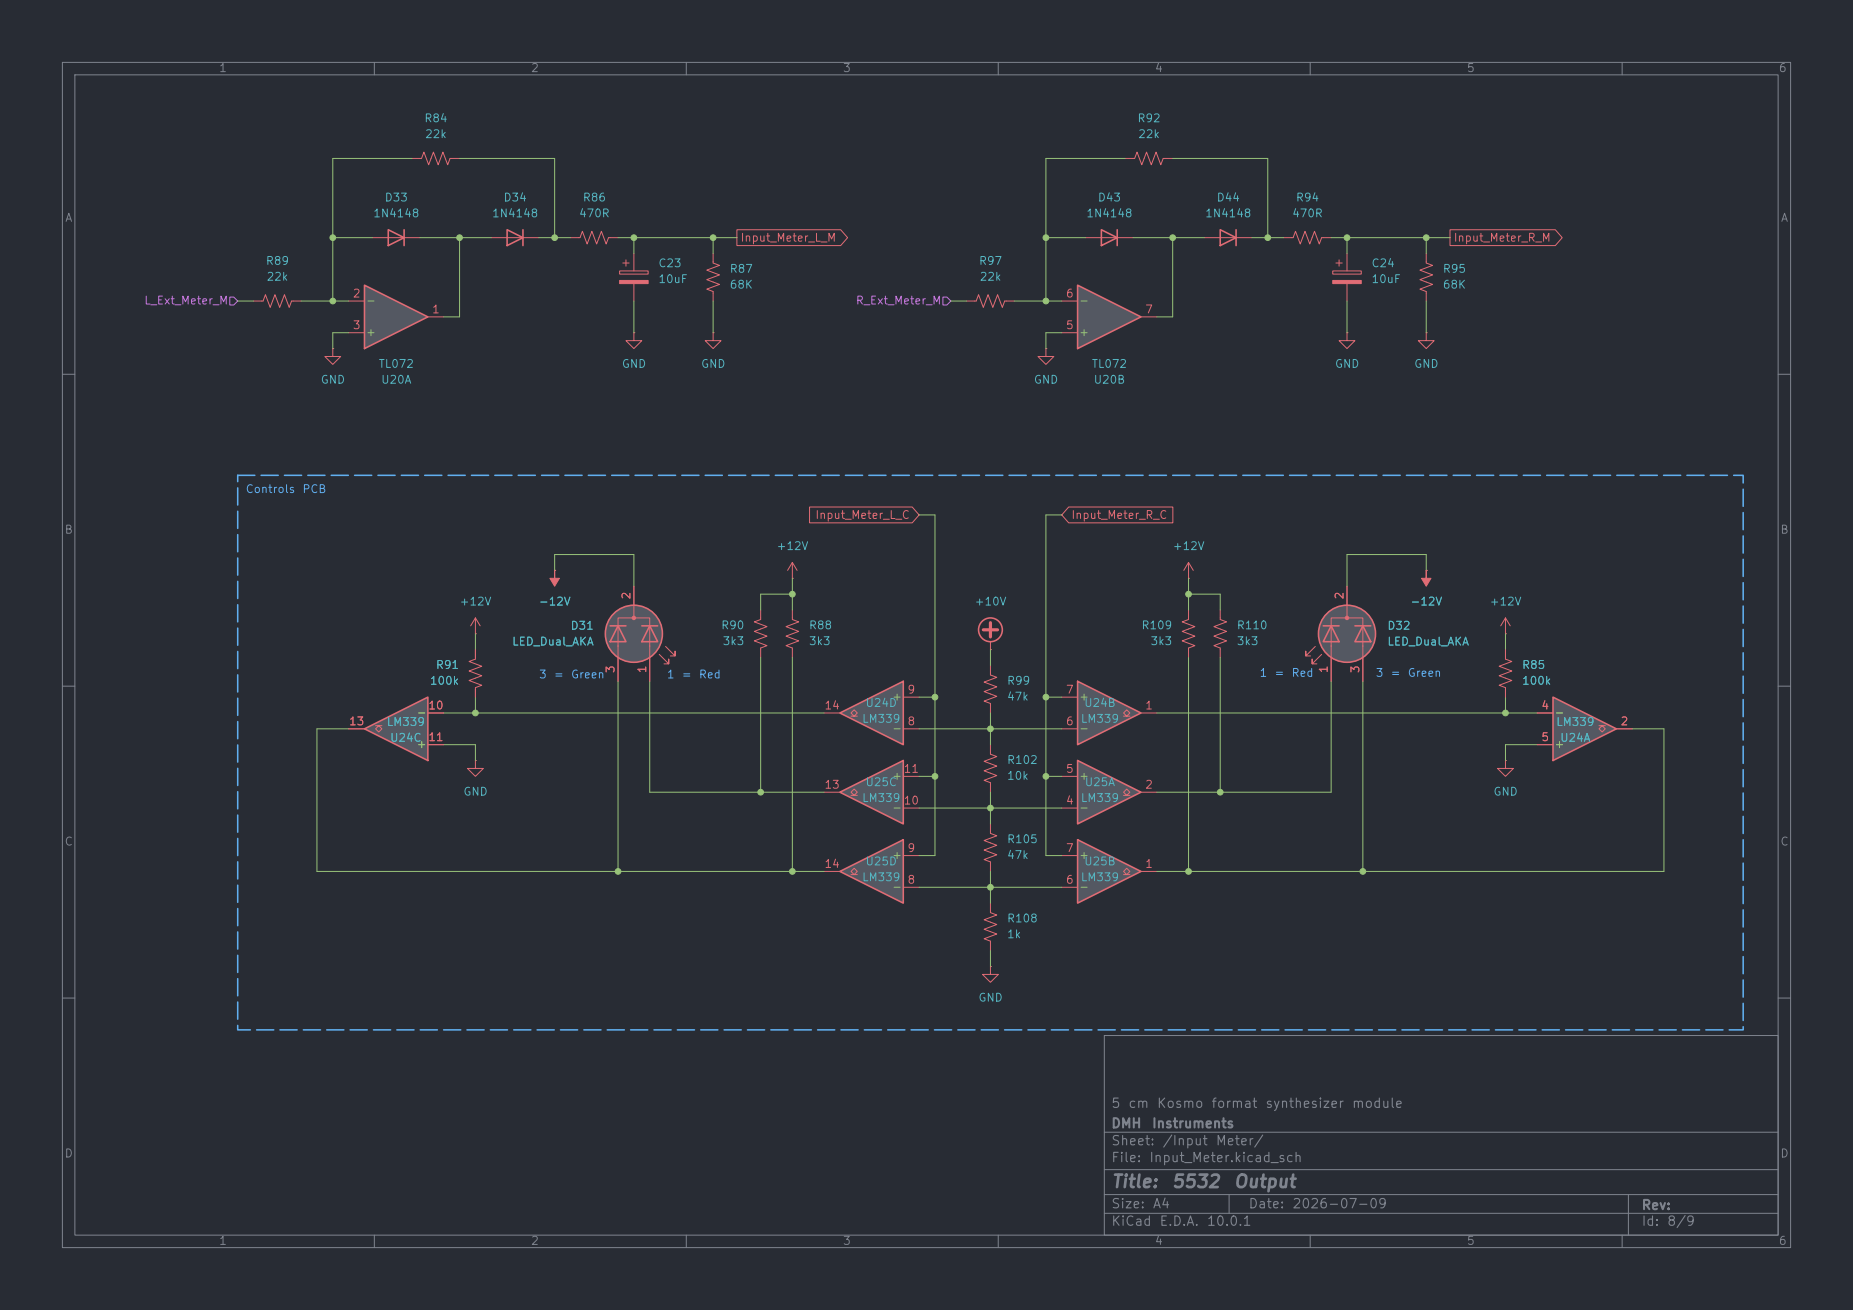
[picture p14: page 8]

5 cm Kosmo format synthesizer module
DMH Instruments
Sheet: /Input Meter/
File: Input_Meter.kicad_sch
Title: 5532 Output

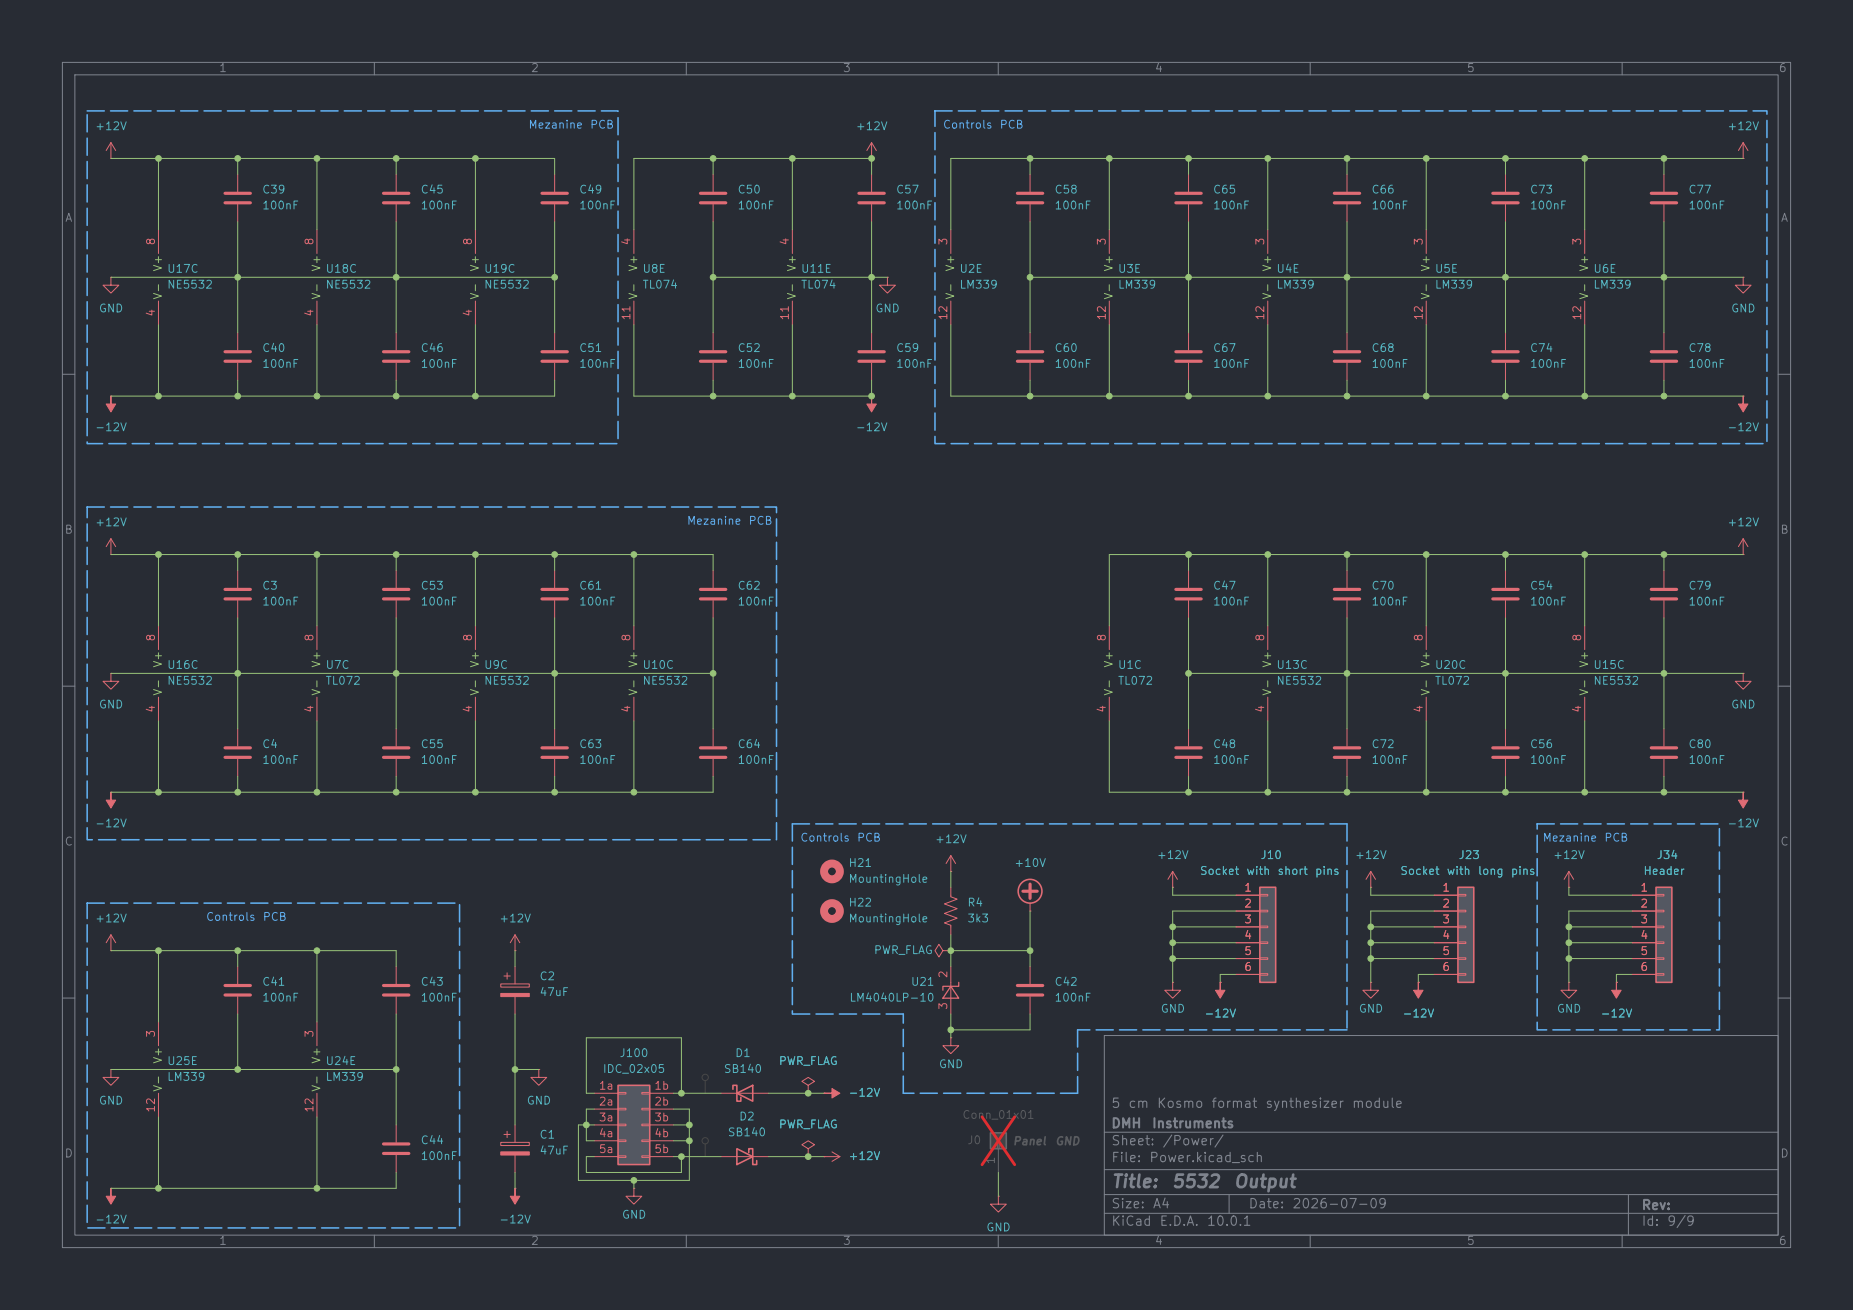
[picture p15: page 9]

Controls PCB Mezanine PCB Mezanine PCB

Socket with short pins 1

Socket with long pins

Socket with long pins 1

5 cm Kosmo format synthesizer module
DMH Instruments
Sheet: /Power/
File: Power.kicad_sch
Title: 5532 Output

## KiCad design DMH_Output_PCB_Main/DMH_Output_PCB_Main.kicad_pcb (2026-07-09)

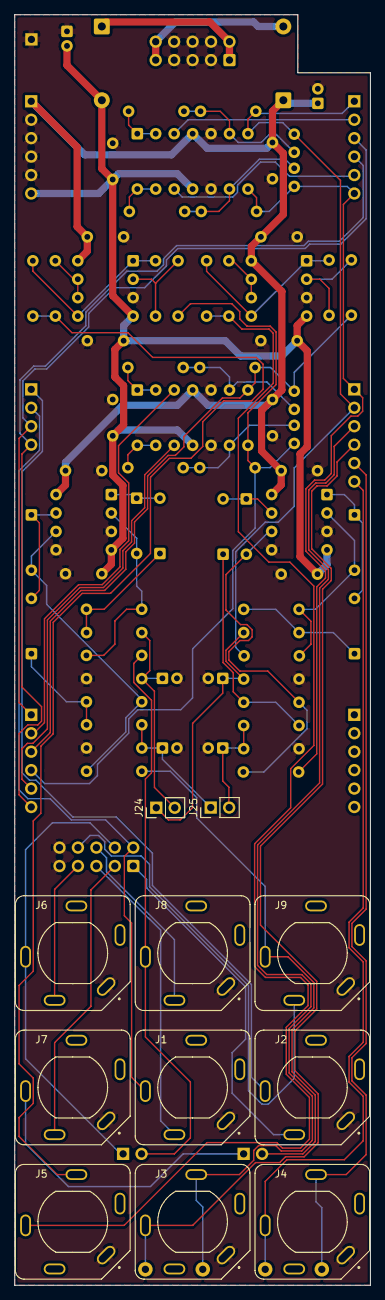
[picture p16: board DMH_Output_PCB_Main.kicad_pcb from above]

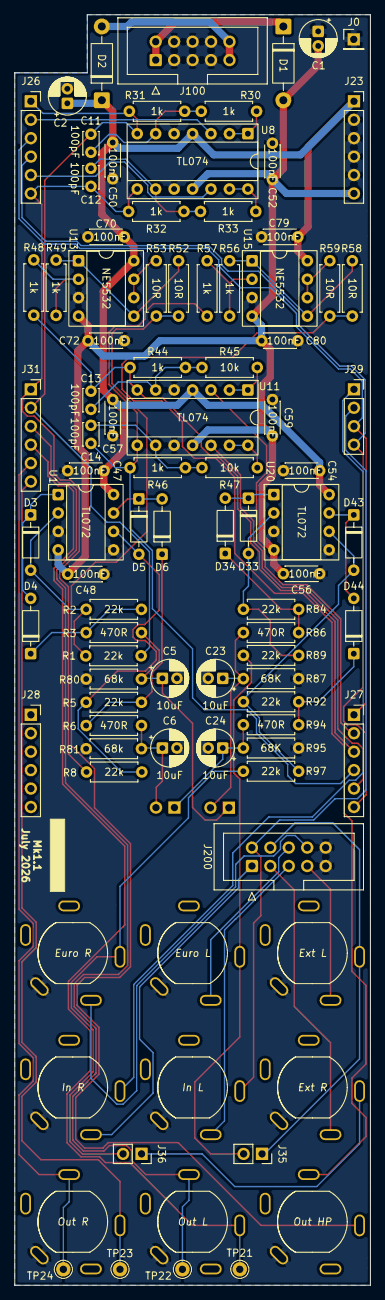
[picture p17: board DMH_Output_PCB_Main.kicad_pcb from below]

Board: 2 copper layers, 49.0 x 175.0 mm, 96 parts (85 on the bottom side), 63 nets.

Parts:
C1, C2: 47uF; CP_Radial_D5.0mm_P2.00mm
C5, C6, C23, C24: 10uF; CP_Radial_D5.0mm_P2.00mm
C11, C12, C13, C14: 100pF; C_Disc_D3.0mm_W2.0mm_P2.50mm
C47, C48, C50, C52, C54, C56, C57, C59, C70, C72, C79, C80: 100nF; C_Disc_D4.3mm_W1.9mm_P5.00mm
D1, D2: SB140; D_DO-41_SOD81_P10.16mm_Horizontal
D3, D4, D5, D6, D33, D34, D43, D44: 1N4148; D_DO-35_SOD27_P7.62mm_Horizontal
J0: Conn_01x01; PinHeader_1x01_P2.54mm_Vertical
J1, J2, J3, J4, J5, J6, J7, J8, J9: TRS_Jack_6.35mm_Sw; CUI_SJ-63083D
J23, J28: Conn_01x06; PinSocket_1x06_P2.54mm_Vertical
J24, J25: Conn_01x02; PinHeader_1x02_P2.54mm_Vertical
J26, J27, J31: Conn_01x06_PinHeader; PinSocket_1x06_P2.54mm_Vertical
J29: Conn_01x04_PinHeader; PinSocket_1x04_P2.54mm_Vertical
J35, J36: Conn_01x02_PinHeader; PinSocket_1x02_P2.54mm_Vertical
J100: IDC_02x05; IDC-Header_2x05_P2.54mm_Vertical_Eurorack
J200: IDC_02x05; IDC-Header_2x05_P2.54mm_Vertical_BackBone
R1, R2, R5, R8, R84, R89, R92, R97: 22k; R_Axial_DIN0207_L6.3mm_D2.5mm_P7.62mm_Horizontal
R3, R6, R86, R94: 470R; R_Axial_DIN0207_L6.3mm_D2.5mm_P7.62mm_Horizontal
R30, R31, R32, R33, R44, R46, R48, R49, R56, R57: 1k; R_Axial_DIN0207_L6.3mm_D2.5mm_P7.62mm_Horizontal
R45, R47: 10k; R_Axial_DIN0207_L6.3mm_D2.5mm_P7.62mm_Horizontal
R52, R53, R58, R59: 10R; R_Axial_DIN0207_L6.3mm_D2.5mm_P7.62mm_Horizontal
R80, R81: 68k; R_Axial_DIN0207_L6.3mm_D2.5mm_P7.62mm_Horizontal
R87, R95: 68K; R_Axial_DIN0207_L6.3mm_D2.5mm_P7.62mm_Horizontal
TP21, TP22, TP23, TP24: TestPoint; Pin_D1.0mm_L10.0mm
U1, U20: TL072; DIP-8_W7.62mm_Socket
U8, U11: TL074; DIP-14_W7.62mm_Socket
U13, U15: NE5532; DIP-8_W7.62mm_Socket

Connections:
+12V: C2.1, C47.1, C50.1, C54.1, C57.1, C70.1, C79.1, D2.1 (K), J23.1, U1.8 (V+), U8.4 (V+), U11.4 (V+), U13.8 (V+), U15.8 (V+), U20.8 (V+)
-12V: C1.2, C48.2, C52.2, C56.2, C59.2, C72.2, C80.2, D1.2 (A), J23.6, U1.4 (V-), U8.11 (V-), U11.11 (V-), U13.4 (V-), U15.4 (V-), U20.4 (V-)
/Balanced Line Driver/L_Bal_OUT_N_M: J3.R (4), J31.3, TP22.1 (1_1)
/Balanced Line Driver/L_Bal_OUT_P_M: J3.T (3), J31.4, TP21.1 (1_1)
/Balanced Line Driver/L_Ch_OUT_M: C11.2, J26.1, J31.2, R1.1, R31.2, U8.7
/Balanced Line Driver/R_Bal_OUT_N_M: J4.R (4), J31.5, TP24.1 (1_1)
/Balanced Line Driver/R_Bal_OUT_P_M: J4.T (3), J31.6, TP23.1 (1_1)
/Balanced Line Driver/R_Ch_OUT_M: C12.2, J26.6, J31.1, R8.1, R32.2, U8.8
/Gain Trimmer/L_Gain_IN_M: J26.3, J27.1, J29.3
/Gain Trimmer/R_Gain_IN_M: J26.4, J27.6, J29.4
/Headphone Amplifier/L_HP_OUT_M: J5.T (3), R52.2, R53.2
/Headphone Amplifier/R_HP_OUT_M: J5.R (4), R58.2, R59.2
/Input Meter/L_Ext_Meter_M: J8.T (3), J35.2, R89.1
/Input Meter/R_Ext_Meter_M: J9.T (3), J36.2, R97.1
/Pre-Gain Stage/L_In_M: J1.T (3), J29.2, J200.6
/Pre-Gain Stage/R_In_M: J2.T (3), J29.1
/PreAmp/L_Ext_IN_M: J6.T (3), J35.1, J200.7
/PreAmp/R_Ext_IN_M: J7.T (3), J36.1
GND: C1.1, C2.2, C5.2, C6.2, C23.2, C24.2, C47.2, C48.1, C50.2, C52.1, C54.2, C56.1, C57.2, C59.1, C70.2, C72.1, C79.2, C80.1, J0.1 (Pin_1_1), J1.S (1), J2.S (1), J3.S (1), J4.S (1), J5.S (1), J6.S (1), J7.S (1), J8.S (1), J9.S (1), J23.2, J23.3, J23.4, J23.5, J100.2a, J100.2b, J100.3a, J100.3b, J100.4a, J100.4b, J200.5, J200.10, R80.1, R81.1, R87.1, R95.1, U1.3 (+), U1.5 (+), U8.5 (+), U8.10 (+), U11.5 (+), U11.10 (+), U13.3 (+), U15.3 (+), U20.3 (+), U20.5 (+)
Input_Meter_L_M: C23.1, J24.2, R86.2, R87.2
Input_Meter_R_M: C24.1, J25.1, R94.2, R95.2
unnamed: D1.1 (K), J100.1a, J100.1b
unnamed: D2.2 (A), J100.5a, J100.5b
unnamed: D3.2 (A), R1.2, R2.1, U1.2 (-)
unnamed: D3.1 (K), D4.2 (A), U1.1
unnamed: D4.1 (K), R2.2, R3.1
unnamed: D5.2 (A), R5.1, R8.2, U1.6 (-)
unnamed: D5.1 (K), D6.2 (A), U1.7
unnamed: D6.1 (K), R5.2, R6.1
unnamed: D33.2 (A), R84.1, R89.2, U20.2 (-)
unnamed: D33.1 (K), D34.2 (A), U20.1
unnamed: D34.1 (K), R84.2, R86.1
unnamed: D43.2 (A), R92.1, R97.2, U20.6 (-)
unnamed: D43.1 (K), D44.2 (A), U20.7
unnamed: D44.1 (K), R92.2, R94.1
unnamed: J1.TN (2), J200.3
unnamed: J2.TN (2), J200.1
unnamed: J26.2, U8.3 (+)
unnamed: J26.5, U8.12 (+)
unnamed: J27.2, U11.3 (+)
unnamed: C13.2, J27.3, R44.2, R48.1, U11.7
unnamed: C14.2, J27.4, R46.2, R57.1, U11.8
unnamed: J27.5, U11.12 (+)
unnamed: J7.TN (2), J200.2
unnamed: J6.TN (2), J200.4
unnamed: J8.TN (2), J200.8
unnamed: J9.TN (2), J200.9
unnamed: R30.1, U8.1, U8.2 (-)
unnamed: C11.1, R30.2, R31.1, U8.6 (-)
unnamed: C12.1, R32.1, R33.2, U8.9 (-)
unnamed: R33.1, U8.13 (-), U8.14
unnamed: R45.1, U11.1, U11.2 (-)
unnamed: C13.1, R44.1, R45.2, U11.6 (-)
unnamed: C14.1, R46.1, R47.2, U11.9 (-)
unnamed: R47.1, U11.13 (-), U11.14
unnamed: R48.2, R49.1, U13.2 (-)
unnamed: R49.2, R52.1, U13.1, U13.5 (+)
unnamed: R53.1, U13.6 (-), U13.7
unnamed: R56.1, R57.2, U15.2 (-)
unnamed: R56.2, R58.1, U15.1, U15.5 (+)
unnamed: R59.1, U15.6 (-), U15.7
Output_Meter_L_M: C5.1, J24.1, R3.2, R80.2
Output_Meter_R_M: C6.1, J25.2, R6.2, R81.2

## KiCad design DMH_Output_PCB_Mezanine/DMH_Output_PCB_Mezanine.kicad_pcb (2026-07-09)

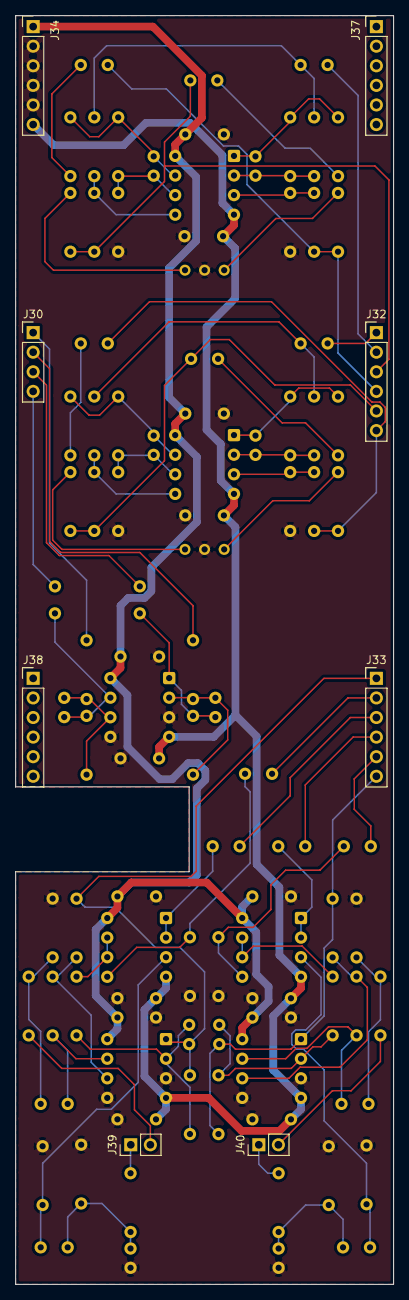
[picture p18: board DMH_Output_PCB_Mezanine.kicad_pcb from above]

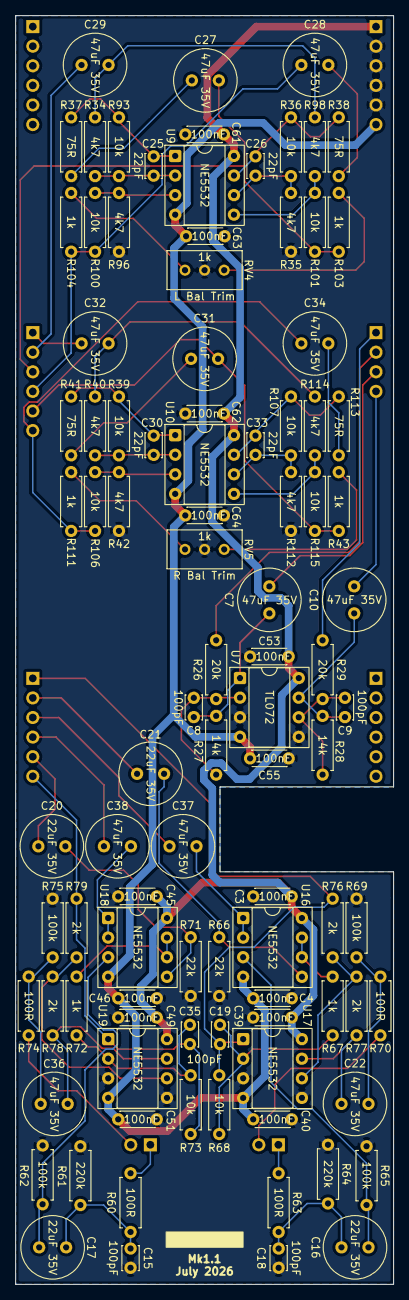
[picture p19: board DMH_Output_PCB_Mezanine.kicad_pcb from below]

Board: 2 copper layers, 49.0 x 164.5 mm, 105 parts (97 on the bottom side), 67 nets.

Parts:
C3, C4, C39, C40, C45, C46, C49, C51, C53, C55, C61, C62, C63, C64: 100nF; C_Disc_D4.3mm_W1.9mm_P5.00mm
C7, C10, C22, C27, C28, C29, C31, C32, C34, C36, C37, C38: 47uF 35V; C_Radial_D8.0mm_H11.5mm_P3.50mm
C8, C9, C15, C18, C19, C35: 100pF; C_Disc_D3.0mm_W2.0mm_P2.50mm
C16, C17, C20, C21: 22uF 35V; C_Radial_D8.0mm_H11.5mm_P3.50mm
C25, C26, C30, C33: 22pF; C_Disc_D3.0mm_W2.0mm_P2.50mm
J30: Conn_01x04_PinHeader; PinHeader_1x04_P2.54mm_Vertical
J32: Conn_01x06_PinHeader; PinHeader_1x06_P2.54mm_Vertical
J33, J34, J37, J38: Conn_01x06; PinHeader_1x06_P2.54mm_Vertical
J39, J40: Conn_01x02_PinHeader; PinHeader_1x02_P2.54mm_Vertical
R26, R29: 20k; R_Axial_DIN0207_L6.3mm_D2.5mm_P7.62mm_Horizontal
R27, R28: 14k; R_Axial_DIN0207_L6.3mm_D2.5mm_P7.62mm_Horizontal
R34, R35, R40, R42, R96, R98, R112, R114: 4k7; R_Axial_DIN0207_L6.3mm_D2.5mm_P7.62mm_Horizontal
R36, R39, R68, R73, R93, R100, R101, R106, R107, R115: 10k; R_Axial_DIN0207_L6.3mm_D2.5mm_P7.62mm_Horizontal
R37, R38, R41, R113: 75R; R_Axial_DIN0207_L6.3mm_D2.5mm_P7.62mm_Horizontal
R43, R67, R72, R103, R104, R111: 1k; R_Axial_DIN0207_L6.3mm_D2.5mm_P7.62mm_Horizontal
R60, R63, R70, R74: 100R; R_Axial_DIN0207_L6.3mm_D2.5mm_P7.62mm_Horizontal
R61, R64: 220k; R_Axial_DIN0207_L6.3mm_D2.5mm_P7.62mm_Horizontal
R62, R65, R69, R75: 100k; R_Axial_DIN0207_L6.3mm_D2.5mm_P7.62mm_Horizontal
R66, R71: 22k; R_Axial_DIN0207_L6.3mm_D2.5mm_P7.62mm_Horizontal
R76, R77, R78, R79: 2k; R_Axial_DIN0207_L6.3mm_D2.5mm_P7.62mm_Horizontal
RV4, RV5: 1k; Potentiometer_Bourns_3296W_Vertical
U7: TL072; DIP-8_W7.62mm_Socket
U9, U10, U16, U17, U18, U19: NE5532; DIP-8_W7.62mm_Socket

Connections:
+12V: C3.1, C39.1, C45.1, C49.1, C53.1, C61.1, C62.1, J34.1, U7.8 (V+), U9.8 (V+), U10.8 (V+), U16.8 (V+), U17.8 (V+), U18.8 (V+), U19.8 (V+)
-12V: C4.2, C40.2, C46.2, C51.2, C55.2, C63.2, C64.2, J34.6, U7.4 (V-), U9.4 (V-), U10.4 (V-), U16.4 (V-), U17.4 (V-), U18.4 (V-), U19.4 (V-)
/PreAmp/RV3A_p1_MZ: C19.2, J33.1, R68.2, R76.1, U17.1
/PreAmp/RV3A_p2_MZ: C21.2, J33.2
/PreAmp/RV3A_p3_MZ: C37.2, J33.3
/PreAmp/RV3B_p4_MZ: C35.2, J33.6, R73.2, R79.1, U19.1
/PreAmp/RV3B_p5_MZ: C20.2, J33.5
/PreAmp/RV3B_p6_MZ: C38.2, J33.4
GND: C3.2, C4.1, C15.1, C18.1, C39.2, C40.1, C45.2, C46.1, C49.2, C51.1, C53.2, C55.1, C61.2, C62.2, C63.1, C64.1, J34.2, J34.3, J34.4, J34.5, R35.1, R42.1, R61.1, R62.1, R64.1, R65.1, R66.1, R69.1, R71.1, R75.1, R96.1, R112.1, RV4.2, RV5.2, U7.3 (+), U7.5 (+), U17.3 (+), U17.5 (+), U19.3 (+), U19.5 (+)
unnamed: C7.1, C8.2, R27.2, U7.1
unnamed: C9.2, C10.1, R28.2, U7.7
unnamed: C15.2, C17.1, R60.2, R61.2
unnamed: C16.1, C18.2, R63.2, R64.2
unnamed: C22.1, R77.2, U17.7
unnamed: C22.2, R69.2, R70.1
unnamed: C25.2, R37.1, R93.2, U9.1
unnamed: C26.2, R36.2, R38.1, U9.7
unnamed: C27.1, R37.2
unnamed: C28.1, R38.2
unnamed: C29.2, R34.1, R98.1
unnamed: C30.2, R39.2, R41.1, U10.1
unnamed: C31.1, R41.2
unnamed: C32.2, R40.1, R114.1
unnamed: C33.2, R107.2, R113.1, U10.7
unnamed: C34.1, R113.2
unnamed: C36.1, R78.2, U19.7
unnamed: C36.2, R74.1, R75.2
unnamed: J30.1, R29.1
unnamed: J30.2, R26.1
unnamed: C7.2, J30.3
unnamed: C10.2, J30.4
unnamed: C32.1, J32.1
unnamed: C29.1, J32.2
unnamed: C27.2, J32.3, R101.2, R103.2
unnamed: C28.2, J32.4, R100.2, R104.1
unnamed: C31.2, J32.5, R43.2, R115.2
unnamed: C34.2, J32.6, R106.2, R111.1
unnamed: J39.1, R63.1
unnamed: J39.2, R70.2
unnamed: J40.1, R60.1
unnamed: J40.2, R74.2
unnamed: R43.1, RV5.3
unnamed: R103.1, RV4.3
unnamed: R104.2, RV4.1
unnamed: R111.2, RV5.1
unnamed: C8.1, R26.2, R27.1, U7.2 (-)
unnamed: C9.1, R28.1, R29.2, U7.6 (-)
unnamed: R96.2, R100.1, U9.3 (+)
unnamed: C25.1, R34.2, R93.1, U9.2 (-)
unnamed: R98.2, R101.1, U9.5 (+)
unnamed: C26.1, R35.2, R36.1, U9.6 (-)
unnamed: R42.2, R106.1, U10.3 (+)
unnamed: C30.1, R39.1, R40.2, U10.2 (-)
unnamed: R114.2, R115.1, U10.5 (+)
unnamed: C33.1, R107.1, R112.2, U10.6 (-)
unnamed: C16.2, R65.2, U16.3 (+)
unnamed: C37.1, U16.1, U16.2 (-)
unnamed: C21.1, R66.2, U16.5 (+)
unnamed: R67.1, U16.6 (-), U16.7
unnamed: C19.1, R67.2, R68.1, U17.2 (-)
unnamed: R76.2, R77.1, U17.6 (-)
unnamed: C17.2, R62.2, U18.3 (+)
unnamed: C38.1, U18.1, U18.2 (-)
unnamed: C20.1, R71.2, U18.5 (+)
unnamed: R72.1, U18.6 (-), U18.7
unnamed: C35.1, R72.2, R73.1, U19.2 (-)
unnamed: R78.1, R79.2, U19.6 (-)

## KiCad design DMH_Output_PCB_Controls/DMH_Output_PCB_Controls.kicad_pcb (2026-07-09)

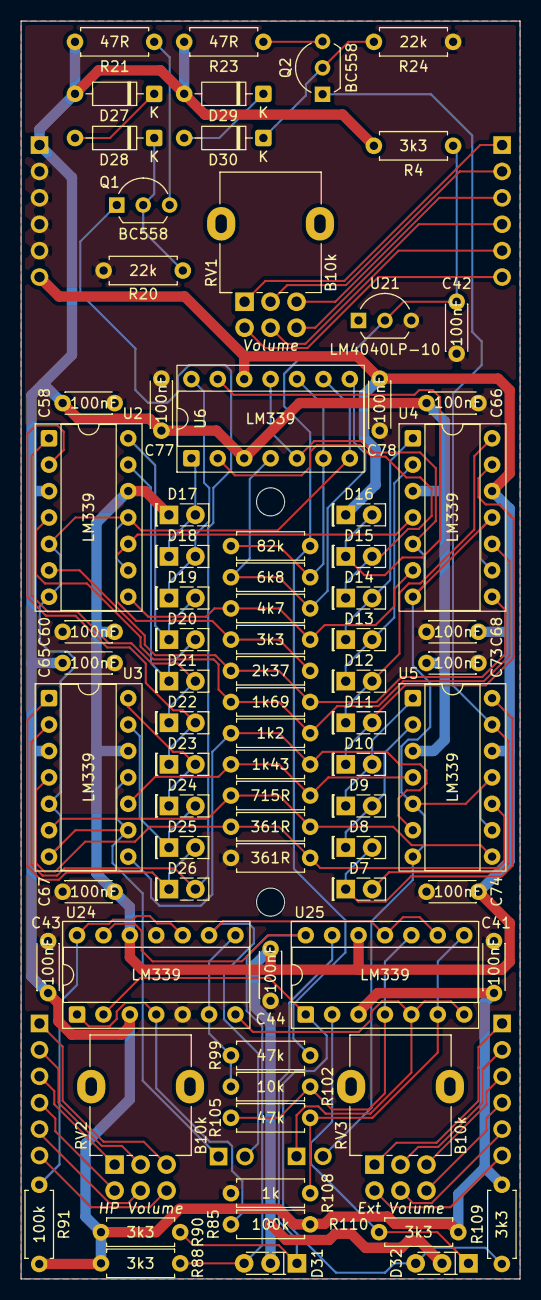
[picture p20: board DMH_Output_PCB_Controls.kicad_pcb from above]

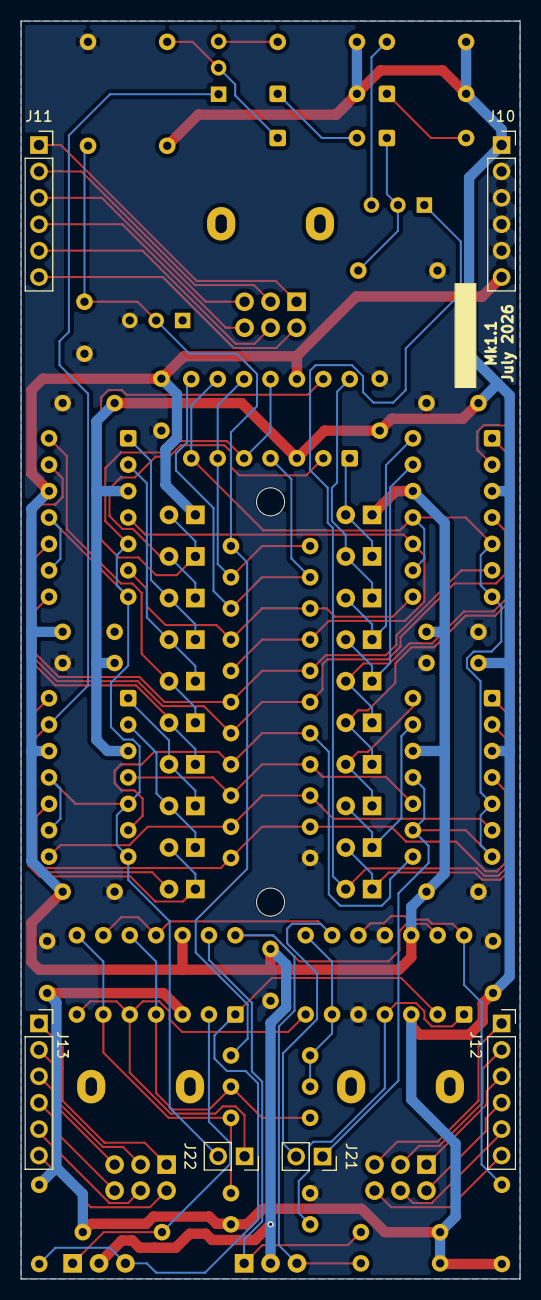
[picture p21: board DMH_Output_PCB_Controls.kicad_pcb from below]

Board: 2 copper layers, 48.0 x 121.0 mm, 87 parts (6 on the bottom side), 71 nets.

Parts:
C41, C42, C43, C44, C58, C60, C65, C66, C67, C68, C73, C74, C77, C78: 100nF; C_Disc_D4.3mm_W1.9mm_P5.00mm
D7, D8, D9, D10, D11, D12, D13, D20, D21, D22, D23, D24, D25, D26: LED_G; LED_Rectangular_W5.0mm_H2.0mm
D14, D15, D18, D19: LED_Y; LED_Rectangular_W5.0mm_H2.0mm
D16, D17: LED_R; LED_Rectangular_W5.0mm_H2.0mm
D27, D28, D29, D30: 1N4148; D_DO-35_SOD27_P7.62mm_Horizontal
D31, D32: LED_Dual_AKA; LED_Rectangular_W5.0mm_H2.0mm-3Pins
H21, H22: MountingHole; MountingHole_2.7mm_M2.5_ISO14580
J10, J13: Conn_01x06; PinSocket_1x06_P2.54mm_Vertical
J11, J12: Conn_01x06_PinHeader; PinSocket_1x06_P2.54mm_Vertical
J21, J22: Conn_01x02; PinSocket_1x02_P2.54mm_Vertical
Q1, Q2: BC558; TO-92L_Inline_Wide
R4, R12, R88, R90, R109, R110: 3k3; R_Axial_DIN0207_L6.3mm_D2.5mm_P7.62mm_Horizontal
R9: 82k; R_Axial_DIN0207_L6.3mm_D2.5mm_P7.62mm_Horizontal
R10: 6k8; R_Axial_DIN0207_L6.3mm_D2.5mm_P7.62mm_Horizontal
R11: 4k7; R_Axial_DIN0207_L6.3mm_D2.5mm_P7.62mm_Horizontal
R13: 2k37; R_Axial_DIN0207_L6.3mm_D2.5mm_P7.62mm_Horizontal
R14: 1k69; R_Axial_DIN0207_L6.3mm_D2.5mm_P7.62mm_Horizontal
R15: 1k2; R_Axial_DIN0207_L6.3mm_D2.5mm_P7.62mm_Horizontal
R16: 1k43; R_Axial_DIN0207_L6.3mm_D2.5mm_P7.62mm_Horizontal
R17: 715R; R_Axial_DIN0207_L6.3mm_D2.5mm_P7.62mm_Horizontal
R18, R19: 361R; R_Axial_DIN0207_L6.3mm_D2.5mm_P7.62mm_Horizontal
R20, R24: 22k; R_Axial_DIN0207_L6.3mm_D2.5mm_P7.62mm_Horizontal
R21, R23: 47R; R_Axial_DIN0207_L6.3mm_D2.5mm_P7.62mm_Horizontal
R85, R91: 100k; R_Axial_DIN0207_L6.3mm_D2.5mm_P7.62mm_Horizontal
R99, R105: 47k; R_Axial_DIN0207_L6.3mm_D2.5mm_P7.62mm_Horizontal
R102: 10k; R_Axial_DIN0207_L6.3mm_D2.5mm_P7.62mm_Horizontal
R108: 1k; R_Axial_DIN0207_L6.3mm_D2.5mm_P7.62mm_Horizontal
RV1, RV2, RV3: B10k; Potentiometer_Alpha_RD902F-40-00D_Dual_Vertical
U2, U3, U4, U5, U6, U24, U25: LM339; DIP-14_W7.62mm_Socket
U21: LM4040LP-10; TO-92L_Inline_Wide

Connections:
+10V: C42.1, R4.1, R9.2, R99.2, U21.2 (K)
+12V: C41.1, C43.1, C58.1, C65.1, C66.1, C73.1, C77.1, D27.2 (A), D29.2 (A), J10.1, R4.2, R21.2, R23.2, R85.2, R88.2, R90.2, R91.2, R109.2, R110.2, U2.3 (V+), U3.3 (V+), U4.3 (V+), U5.3 (V+), U6.3 (V+), U24.3 (V+), U25.3 (V+)
-12V: C44.2, C60.2, C67.2, C68.2, C74.2, C78.2, D16.1 (K), D17.1 (K), D31.2 (K), D32.2 (K), J10.6, U2.12 (V-), U3.12 (V-), U4.12 (V-), U5.12 (V-), U6.12 (V-), U24.12 (V-), U25.12 (V-)
/PreAmp/RV3A_p1_C: J13.1, RV3.1
/PreAmp/RV3A_p2_C: J13.2, RV3.2
/PreAmp/RV3A_p3_C: J13.3, RV3.3
/PreAmp/RV3B_p4_C: J13.6, RV3.4
/PreAmp/RV3B_p5_C: J13.5, RV3.5
/PreAmp/RV3B_p6_C: J13.4, RV3.6
GND: C41.2, C42.2, C43.2, C44.1, C58.2, C60.1, C65.2, C66.2, C67.1, C68.1, C73.2, C74.1, C77.2, C78.1, J10.2, J10.3, J10.4, J10.5, R19.1, R20.1, R24.1, R108.1, U21.3 (A), U24.5 (+), U24.11 (+)
Input_Meter_L_C: J21.2, U24.9 (+), U25.9 (+), U25.11 (+)
Input_Meter_R_C: J22.1, U24.7 (+), U25.5 (+), U25.7 (+)
unnamed: D7.2 (A), Q2.1 (C), U5.13
unnamed: D7.1 (K), D8.2 (A), U5.14
unnamed: D8.1 (K), D9.2 (A), U5.2
unnamed: D9.1 (K), D10.2 (A), U5.1
unnamed: D10.1 (K), D11.2 (A), U4.13
unnamed: D11.1 (K), D12.2 (A), U4.14
unnamed: D12.1 (K), D13.2 (A), U4.2
unnamed: D13.1 (K), D14.2 (A), U4.1
unnamed: D14.1 (K), D15.2 (A), U6.2
unnamed: D15.1 (K), D16.2 (A), U6.13
unnamed: D17.2 (A), D18.1 (K), U6.1
unnamed: D18.2 (A), D19.1 (K), U6.14
unnamed: D19.2 (A), D20.1 (K), U2.14
unnamed: D20.2 (A), D21.1 (K), U2.13
unnamed: D21.2 (A), D22.1 (K), U2.1
unnamed: D22.2 (A), D23.1 (K), U2.2
unnamed: D23.2 (A), D24.1 (K), U3.14
unnamed: D24.2 (A), D25.1 (K), U3.13
unnamed: D25.2 (A), D26.1 (K), U3.1
unnamed: D26.2 (A), Q1.1 (C), U3.2
unnamed: D27.1 (K), D28.2 (A)
unnamed: D28.1 (K), Q1.2 (B), R20.2
unnamed: D29.1 (K), D30.2 (A)
unnamed: D30.1 (K), Q2.2 (B), R24.2
unnamed: D31.1 (A1), R90.1, U25.13
unnamed: D31.3 (A2), R88.1, U24.13, U25.14
unnamed: D32.1 (A1), R110.1, U25.2
unnamed: D32.3 (A2), R109.1, U24.2, U25.1
unnamed: J11.1, RV1.1
unnamed: J11.2, RV1.2
unnamed: J11.3, RV1.3
unnamed: J11.4, RV1.6
unnamed: J11.5, RV1.5
unnamed: J11.6, RV1.4
unnamed: J12.1, RV2.3
unnamed: J12.2, RV2.2
unnamed: J12.3, RV2.1
unnamed: J12.4, RV2.4
unnamed: J12.5, RV2.5
unnamed: J12.6, RV2.6
unnamed: Q1.3 (E), R21.1
unnamed: Q2.3 (E), R23.1
unnamed: R14.1, R15.2, U2.4 (-), U4.10 (-)
unnamed: R13.1, R14.2, U2.6 (-), U4.8 (-)
unnamed: R12.1, R13.2, U2.10 (-), U4.4 (-)
unnamed: R11.1, R12.2, U2.8 (-), U4.6 (-)
unnamed: R18.1, R19.2, U3.4 (-), U5.10 (-)
unnamed: R17.1, R18.2, U3.6 (-), U5.8 (-)
unnamed: R16.1, R17.2, U3.10 (-), U5.4 (-)
unnamed: R15.1, R16.2, U3.8 (-), U5.6 (-)
unnamed: R10.1, R11.2, U6.4 (-), U6.8 (-)
unnamed: R9.1, R10.2, U6.6 (-), U6.10 (-)
unnamed: R85.1, U24.1, U24.4 (-)
unnamed: R99.1, R102.2, U24.6 (-), U24.8 (-)
unnamed: R91.1, U24.10 (-), U24.14
unnamed: R102.1, R105.2, U25.4 (-), U25.10 (-)
unnamed: R105.1, R108.2, U25.6 (-), U25.8 (-)
Output_Meter_L_C: J21.1, U2.5 (+), U2.7 (+), U2.9 (+), U2.11 (+), U3.5 (+), U3.7 (+), U3.9 (+), U3.11 (+), U6.7 (+), U6.9 (+)
Output_Meter_R_C: J22.2, U4.5 (+), U4.7 (+), U4.9 (+), U4.11 (+), U5.5 (+), U5.7 (+), U5.9 (+), U5.11 (+), U6.5 (+), U6.11 (+)

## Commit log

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2025-10-16 Panel design in progress
    [DMH_Output_PANEL.kicad_pcb, DMH_Output_PANEL.kicad_sch]
2025-10-16 Front panel design in progress
    [DMH_Output_PANEL.kicad_pcb, DMH_Output_PANEL.kicad_sch]
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2025-10-17 Finished front panel design
    [DMH_Output_PANEL.kicad_pcb, DMH_Output_PANEL.kicad_sch]
2025-11-23 Created PCB 1 project
    [Core_Circuit.kicad_sch, DMH_Output_PCB_1.kicad_pcb, DMH_Output_PCB_1.kicad_sch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]
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2025-12-12 Designed external input meter
    [DMH_Output_PCB_1.kicad_sch, Input_Meter.kicad_sch, Output_Meter.kicad_sch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]
2025-12-14 Changed balanced output for quasi-floating design
    [Balanced_line_driver.kicad_sch, Input_Meter.kicad_sch]
2025-12-14 Redesigned external input preamp
    [Balanced_line_driver.kicad_sch, DMH_Output_PCB_1.kicad_sch, Gain_trimmer.kicad_sch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]
2025-12-15 Create dBu meter calculation.xlsx
    [dBu meter calculation.xlsx]
2025-12-15 Update dBu meter calculation.xlsx
    [dBu meter calculation.xlsx]
2025-12-17 Updated output meter peak detectors
    [Balanced_line_driver.kicad_sch, Output_Meter.kicad_sch, PreAmp.kicad_sch]
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2025-12-19 Updated meters resistor values
    [DMH_Output_PCB_1.kicad_sch, Headphone_amplifier.kicad_sch, Input_Meter.kicad_sch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]
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2025-12-22 Linked TRS jacks footprint
    [DMH_Output_PCB_1.kicad_sch]
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2026-03-03 Starting design of Controls PCB
    [Balanced_line_driver.kicad_sch, Core_Circuit.kicad_sch, DMH_Output_PANEL.kicad_pcb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]
2026-03-04 Simulated 10V ref for VU meter
    [Output_Meter.kicad_sch, dBu meter calculation.xlsx]
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2026-03-07 Starting Controls PCB design
    [DMH_Output_PCB_Controls.kicad_pcb, Gain_trimmer.kicad_sch, Headphone_amplifier.kicad_sch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]
2026-03-07 Controls PCB placement ongoing
    [Balanced_line_driver.kicad_sch, DMH_Output_PANEL.kicad_pcb, DMH_Output_PCB_Controls.kicad_pcb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]
2026-03-08 Controls PCB placement in progress
    [DMH_Output_PCB_Controls.kicad_pcb, Power.kicad_sch]
2026-03-08 Controls PCB comp placement done
    [DMH_Output_PCB_Controls.kicad_pcb, Gain_trimmer.kicad_sch, Headphone_amplifier.kicad_sch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]
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2026-03-09 Controls PCB routing ongoing
    [DMH_Output_PCB_Controls.kicad_pcb, DMH_Output_PCB_Controls.kicad_sch]
2026-03-09 Clarifying inter PCB connectors in progress
    [DMH_Output_PCB_Controls.kicad_sch, Gain_trimmer.kicad_sch, Input_Meter.kicad_sch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]
2026-03-09 Clarified interPCB connectors in schematic
    [Gain_trimmer.kicad_sch, Headphone_amplifier.kicad_sch, PreAmp.kicad_sch]
2026-03-09 Controls PCB routing in progress
    [DMH_Output_PCB_Controls.kicad_pcb, DMH_Output_PCB_Controls.kicad_sch, Headphone_amplifier.kicad_sch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]
2026-03-09 Controls PCB Routing done
    [DMH_Output_PCB_Controls.kicad_pcb]
2026-03-10 Created LEDs baffle PCB
    [Balanced_line_driver.kicad_sch, Core_Circuit.kicad_sch, DMH_Output_PCB_LEDs.kicad_pcb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]
2026-03-10 Created Main PCB project
    [Balanced_line_driver.kicad_sch, Core_Circuit.kicad_sch, DMH_Output_PCB_Controls.kicad_pcb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]
2026-03-10 Preparing for split in submodules
    [DMH_Output_PCB_Main.kicad_pcb, Power.kicad_sch]
2026-03-10 Generated Gerbers for prototyping
    Panel, Controls and LEDs only
    [DMH_Output_PANEL-B_Cu.gbl, DMH_Output_PANEL-B_Mask.gbs, DMH_Output_PANEL-B_Paste.gbp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]
2026-03-17 Regenerated LEDs baffle Gerbers
    Added second GND plated hole to avoid issues with the probe test at JLC
    [DMH_Output_PCB_LEDs-B_Cu.gbl, DMH_Output_PCB_LEDs-B_Mask.gbs, DMH_Output_PCB_LEDs-B_Paste.gbp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]
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2026-04-25 Removed 2 extra OpAmps from the headphone amp
    [Balanced_line_driver.kicad_sch, DMH_Output_PCB_Controls.kicad_sch, DMH_Output_PCB_Main.kicad_sch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]
2026-04-26 Changed headphone amp max gain
    [Headphone_amplifier.kicad_sch]
2026-04-27 Replaced jack symbols with 5pin ones
    Also updated Meter LED current source resistor to 75R
    Also increased LED guiding PCB mounting holes to M2.5
    [Balanced_line_driver.kicad_sch, DMH_Output_PCB_Controls.kicad_pcb, DMH_Output_PCB_Controls.kicad_sch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]
2026-05-02 Prep for Main and MZ PCBs design in progress
    [Balanced_line_driver.kicad_sch, DMH_Output_PCB_Controls.kicad_sch, DMH_Output_PCB_Main.kicad_pcb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]
2026-05-02 Prepped for Main PCB design
    [Balanced_line_driver.kicad_sch, DMH_Output_PCB_Main.kicad_pcb, DMH_Output_PCB_Main.kicad_sch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]
2026-05-02 Prepped for Main PCB comp placement
    [Balanced_line_driver.kicad_sch, Core_Circuit.kicad_sch, DMH_Output_PCB_Mezanine.kicad_pcb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]
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2026-05-03 Main PCB comp placement in progress
    [DMH_Output_PCB_Main.kicad_pcb]
2026-05-03 PCB Main comp placement done
    [DMH_Output_PCB_Main.kicad_pcb, Input_Meter.kicad_sch, PreAmp.kicad_sch]
2026-05-03 Main PCB routing in progress
    [DMH_Output_PCB_Main.kicad_pcb]
2026-05-04 Main PCB routing done
    [DMH_Output_PCB_Controls.kicad_pcb, DMH_Output_PCB_Controls.kicad_sch, DMH_Output_PCB_Main.kicad_pcb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]
2026-05-04 Started Mezanine PCB project
    [Balanced_line_driver.kicad_sch, Core_Circuit.kicad_sch, DMH_Output_PCB_Mezanine.kicad_pcb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]
2026-05-04 Defined Mezanine PCB outer limits
    [DMH_Output_PCB_Main.kicad_pcb, DMH_Output_PCB_Mezanine.kicad_pcb]
2026-05-07 Placed PreAmp components on PCB
    [DMH_Output_PCB_Mezanine.kicad_pcb]
2026-05-10 Placed pre-gain stage components
    [DMH_Output_PCB_Mezanine.kicad_pcb]
2026-05-10 Mezanine PCB comp placement done
    [Balanced_line_driver.kicad_sch, DMH_Output_PCB_Mezanine.kicad_pcb]
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2026-05-13 Mezanine PCB routing done
    [DMH_Output_PCB_Mezanine.kicad_pcb]
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2026-07-01 Fixed 22k resistor value
    [Input_Meter.kicad_sch]
2026-07-05 Adjusted output meter resistors
    ... and deleted unnecessary notes
    [DMH_Output_PCB_Controls-B_Cu.gbl, DMH_Output_PCB_Controls-B_Mask.gbs, DMH_Output_PCB_Controls-B_Paste.gbp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]
2026-07-09 Inverted line outputs hot and cold pins
    ... in order to avoid phase inversion at the TRS jack tip.
    [Balanced_line_driver.kicad_sch, DMH_Output_PCB_Controls.kicad_pcb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]
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
